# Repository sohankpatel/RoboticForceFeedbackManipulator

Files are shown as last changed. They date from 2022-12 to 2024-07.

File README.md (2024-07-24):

# RoboticForceFeedbackManipulator
Final Project for ECE 445, Manipulator with user force-feedback

This is a project I did for my Senior Design class

It is a Robotic manipulator and glove system meant to allow the wearer to "feel" forces from the robotic hand

Details are contained in the Final Paper

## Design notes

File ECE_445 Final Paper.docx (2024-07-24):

By

Noah Franceschini

Sohan Patel

Final Report for ECE 445, Senior Design, Fall 2022

TA: Jason Paximadas

6 December 2022

Project No. 3

HAPTIC FEEDBACK GLOVE

Abstract

Our project was a user-worn device similar to a VR haptic feedback glove. It is designed to apply a variety of forces back to a user depending on the force exerted by a separate manipulator. We created the user-worn device as well as a rudimentary gripper. We were able to implement a finger tracking algorithm, and developed a method to measure force applied by the manipulator and apply it back to a user's hand. We were unable to get force feedback fully working due to unforeseen issues with electronics chosen for the project.

Contents

1. Introduction 1

1.1 Subsystem Overview 1

2. Design 3

2.1 Design Procedure 3

2.2 Design Details 3

3. Verification 7

3.1 Glove 7

3.2 Manipulator 8

3.3 Microcontroller 9

3.4 Power 9

4. Costs 11

4.1 Parts 11

4.2 Labor 12

5. Conclusion 14

5.1 Accomplishments 14

5.2 Uncertainties 14

5.3 Ethical considerations 15

5.4 Future work 15

References 16

Appendix A Requirement and Verification Table 17

# 1. Introduction

From Zoom calls for work and instructional material, to YouTube videos where we can explore vast worlds through our screen, the way we interact with our world has become increasingly virtualized, but only in sight and sound. It is difficult to interact with objects through a screen such that if a material is not immediately in front of you then there is no good way to feel its physical properties. Our solution to this problem is the haptic feedback glove.

The haptic feedback system comes in two distinguishable parts: a robotic manipulator and a wearable glove. The robotic manipulator is a 3D printed robotic hand controlled via servos. The robotic fingers’ positions mimic that of the user’s hand in the glove and each finger reports back its current draw to tell the glove system how much force the servos are applying on whatever object the manipulator is holding. As for the glove, it applies forces read from the manipulator system back onto the user’s hand as to recreate a sense of touch from the manipulator’s held object, thus allowing users to interact with objects from a distance.

Throughout this report, we detail the intended design aspects of our project and how the system should cohesively mesh into the final product. Though, despite our best efforts, our end product did not hit the goals that we wanted it to. We were unable to get the force feedback part of the glove working properly; however, we were able to successfully implement finger tracking as well as successfully implement all of our components on our printed circuit board (PCB).

## 1.1 Subsystem Overview

There are four main components to our system: the glove subsystem and the manipulator subsystem, the microcontroller subsystem, and the power subsystem. The glove subsystem is a wearable device that is responsible for applying forces to the user’s hand and keeping track of the user’s finger position. The manipulator subsystem is a 3D-printed robotic hand that mimics the glove’s finger positions and relays forces back to the glove subsystem. The microcontroller subsystem is the mediator of the glove and manipulator subsystem as it receives both the position and force information from both systems and tells each respective subsystem where it should be and what forces it should be applying. As for the power subsystem, that consists of a lithium-polymer (LiPO) battery that powers our entire PCB through a buck converter as well as the electronic speed controllers (ESC) that we use for our brushless motors.

To consider this project successful, we instituted these requirements that must be met by our design:

- Measure and apply forces back to user’s hand to at least 10 lbs of force
- Have a latency of less than 1 second
- Support dynamically changing the force to match anything from slight resistance to fully stopping movement

Our reasoning for these requirements hinges on what we believed would create a quality experience for the user. We wanted to apply at least 10 lbs of force back to the user as that is about the pinch strength of most people [1], where pinch strength is the measure between what a person can hold between a finger and a thumb, and we wish to restrain the users movement of up to that amount of force. For the user to have a responsive experience with the glove, we figured that a full control loop should take less than a second. Lastly, we wanted our glove to provide a range of forces as to allow the user to have a better feel for what the manipulator was interacting with. The range of forces should allow the user to tell whether the manipulator is encountering a solid object or something softer like a stress ball.

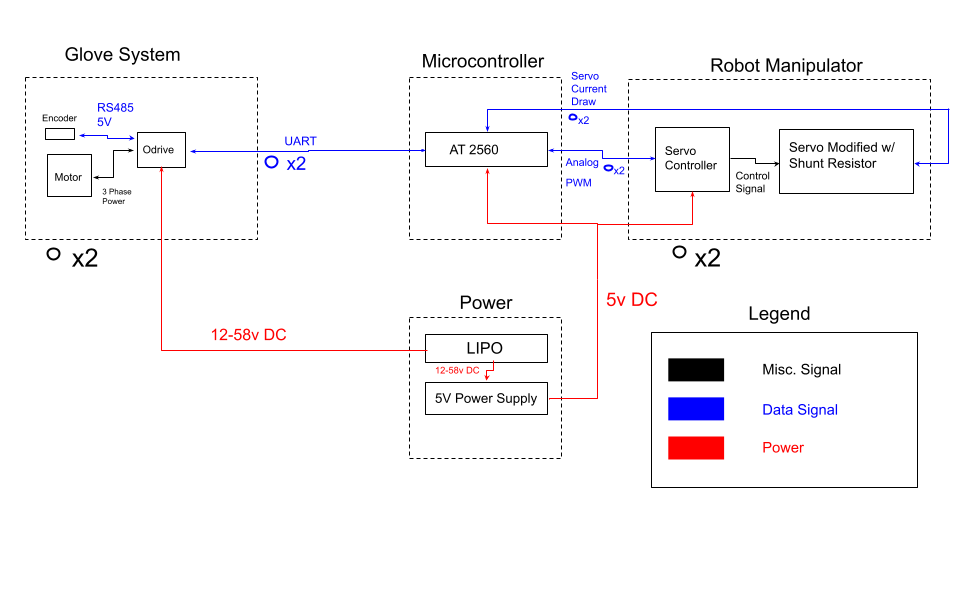
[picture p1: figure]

Figure 1: Project block diagram

# 2. Design

## 2.1 Design Procedure

### 2.1.1 Glove

We originally decided to use servos to apply forces to the user’s hand, but they are not able to change forces, nor report back position without extensive modifications. We then looked into brushless motors and their controllers and found a few options: ESC, VESC [2] and ODrive [3]. ESCs, while cheap, can't support encoders and therefore can’t measure motor position. VESCs do support encoders and are readily available, but low-cost designs use a chip in the DRV family from Texas Instruments that is in shortage at the time of this report, so we were unable to source them. The final option was ODrive, it is a robust system that has very precise control over torque and can be communicated with over the universal asynchronous receiver-transmitter protocol (UART) to send position information, the downside is that they are quite pricey and require a fair bit of configuration before use.

### 2.1.2 Manipulator

We decided on using simple hobby servos for this component. The alternatives would have been another controller with precise positioning like the ODrive, but we felt it would be overkill for our purposes.

### 2.1.3 Microcontroller

The microcontroller originally needed to support 5 UART devices, the only Atmel product we found that was readily available, well documented and inexpensive was the ATmega2560 [4]. The PCB also had a high side current sensing circuit that will be discussed in detail in a later section.

### 2.1.4 Power

The power system had a couple requirements. The first being 12-58V DC and 120A to the ODrives, the best candidate for this would be a LiPO battery, as they support the high discharge rate and a 6s battery has a voltage of 22.2V.

## 2.2 Design Details

### 2.2.1 Glove

The glove was relatively simple to design, as ODrives can do all that we need them too right from the factory. They are able to communicate with the AMT212B-V encoder over RS485 with some slight configuration. Using the ODrive and this encoder, we not only can drive the motor to an extremely precise position, we can also poll it via UART for that position. These UART messages are created using the ODrive Arduino library [3], which turned out to have bugs that we corrected. More specifically, the command for getting the encoder position was incorrect. It outputs this position as a positive or negative number in units of full rotations, so .5 would be a half turn clockwise. We controlled the force on the user's hand by setting the ODrive to a low current cutoff, just enough to take up slack in the strings attached to the user’s fingers. We can then increase this cutoff via UART proportionally to the current consumed by the servos to pull back with increasing intensity on the wearer’s hand. We found that 40A of current is enough to reach 10 lbs of force on the user’s hand, with the correlation being roughly linear down to zero force. The motors and encoders were mounted to an arm sleeve, with strings attached to fingers of a glove.

### 2.2.2 Manipulator

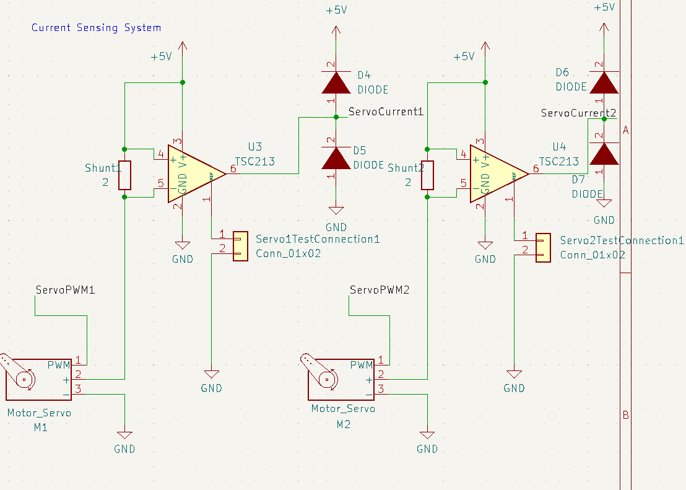
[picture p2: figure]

Figure 2: Current Sensing Circuit

The manipulator was one of the most important parts of our project, as it is where the entire idea of force feedback comes from. The manipulator was moved with servos that had high side shunt resistors. The voltage across these resistors is proportional to current via Ohm’s Law. We can’t drop the full 5V across this resistor however, as the servos pull 3A. This would lead to a 15W power dissipation which is quite high and it would be difficult to find resistors rated for that power. It would also mean we would have to consider other factors such as heat sinking or actively cooling the board. Because of this, we decided on a lower voltage drop of .1V. We chose a resistor of 30 mΩ. This allows us to drop just under .1V at 3A of current, at a much lower power dissipation. The issue with this is that the analog to digital converter (ADC) in the microcontroller unit (MCU) is only 10 bits, it can only read 1024 values. If we were to use the .1V directly, we would only be able to cover 20 discrete values. The concern we had was that this would lead to distinct steps that the user could feel as the force increased. In order to mitigate this, we decided to use an amplifier circuit to increase that .1V to the full 5V range, in order to take advantage of the full range of the ADC (Figure 2). We used a TSC213 [5] integrated circuit (IC), which has a gain of 50, which nicely landed us in the 5V range. There are some additional diodes in the schematic that are for protecting the MCU in the case that the voltage goes over 5V and could damage the ADC, but they were left out in the final PCB.

### 2.2.3 Microcontroller

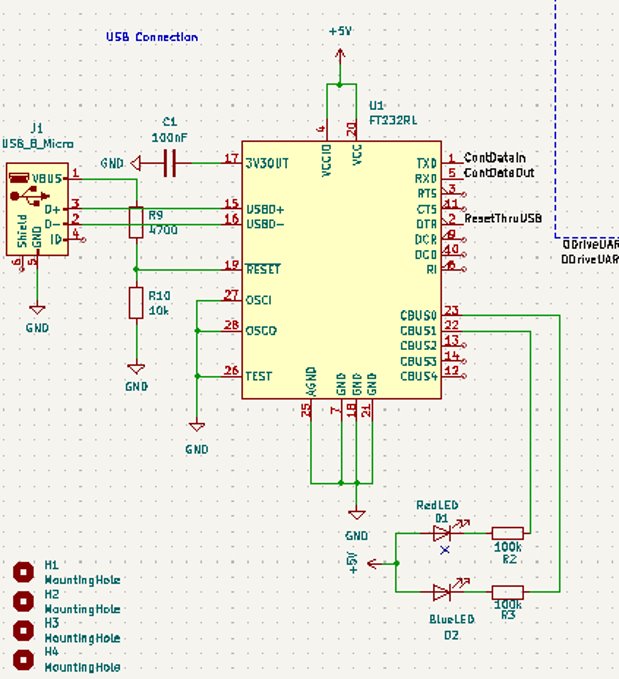
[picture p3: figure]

Figure 3: FTDI programming circuit

The microcontroller we chose was the Atmel ATMEGA2560. It was chosen because not only is it the same processor as an Arduino Mega, it is also capable of five UART connections at once. This was more important in our original design with five ODrives, but most arduino boards do not support more than one UART device. We wanted to use a MCU that was also on an Arduino board so we could flash an Arduino bootloader and program it via the Arduino integrated development environment (IDE). This would also allow us to stream serial information back to our computer for debugging. To do this we used a chip from FTDI that uses UART 0 on the MCU to flash programs (Figure 3). We also exposed the MCUs in-circuit serial programming (ICSP) pins and joint test action group (JTAG) pins in the case that the USB programming chip failed. We used the ICSP pins to flash the Arduino bootloader to the board and were able to program it over USB. However, we ended up not using the FTDI programmer in the final project because we found it easier to just flash over ICSP using an Arduino Uno.

### 2.2.4 Power

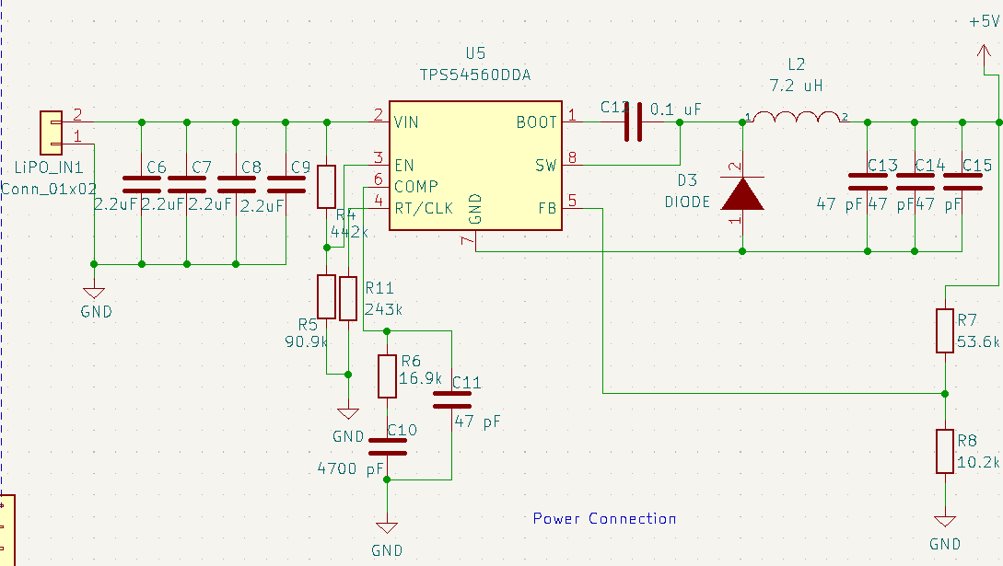
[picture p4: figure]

Figure 4: Buck Converter circuit

The power subsystem was quite simple. We chose a 6S, 5Ah, 45C LiPO to power the entire project. It can provide 22.2V at 5*45A, which is 225A, far more than the 120A we need. However the microcontroller only runs on 5V. We needed to step down the voltage and had 2 options, a linear regulator or buck converter. We ended up using a buck converter because a linear regulator would have to dissipate a large amount of power and would likely need to be cooled and would cause us to need additional design considerations, similarly to if we tried to dissipate 15W across a resistor. We chose a TPS54560DDA [6] chip from TI. It has an input voltage of up to 60V and can output 5V at 5A, which should be enough to run our entire project. The downside of it compared to a linear regulator is that it needs a fair amount of surrounding circuitry (Figure 4) in order to set the device’s parameters. We also found that we should have added large output capacitors due to the transient loads produced by the servos turning on that ended up browning out the MCU.

# 3. Verification

## 3.1 Glove

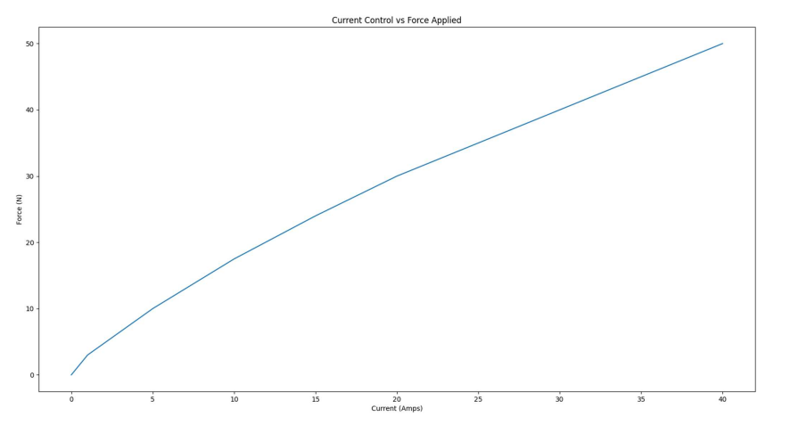
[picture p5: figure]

Figure 5: Current vs Force

The glove subsystem verifications were quite straightforward, to test UART we not only used an arduino mega to send commands, we also used an oscilloscope to view the waveforms. We were actually able to find an error in the ODrive Arduino library thanks to this. When we were receiving nothing in response when polling for encoder position, we decided to decode the UART signal and found that the ODrive was responding with random values. Upon diving deeper we found that the command being sent with the GetPosition() function was deprecated and meant for the old open-source ODrive 3.6, whereas we were using ODrive Pro. Figure 5 contains the forces we measured from the ODrive when applying various currents. Interestingly, this is somewhat linear which was not expected due to motor torque vs current not generally following a linear pattern. We were easily able to apply 10 lbs of force and could likely apply more, as the ODrive is capable of 60A sustained without external cooling. The final verification was if the glove could actually stop the user’s hand completely, we found that this was absolutely the case. When wearing the glove and attempting to close our hands it was easily able to keep them open with the 40A current value, which applied 50N of force.

## 3.2 Manipulator

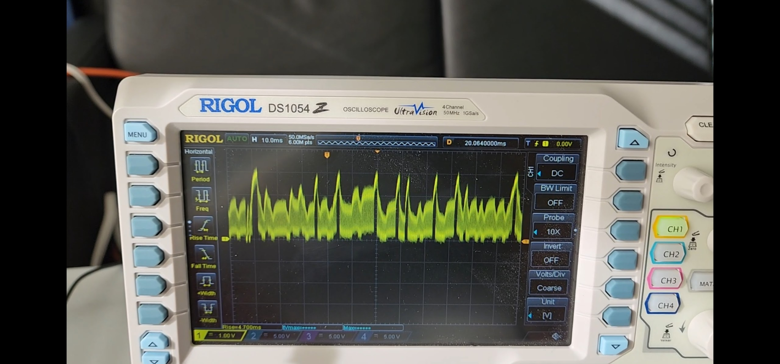
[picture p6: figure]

Figure 6: Oscilloscope output of current draw

The manipulator was a bit more involved to debug, but was a similar process to the glove when testing servo communication via pulse width modulation (PWM). We measured the output of our PCB using an oscilloscope and found that it was, in fact, varying the PWM duty cycle in a way the servo could understand. We tested by sweeping it from 0 to 180 degrees and found that it did follow precisely. We were also able to get it to mimic finger positions quite easily by polling the ODrive encoder position and converting it to an angle between 0 and 180, then commanding the servo to that location. The most difficult part to verify was the voltage across our shunt resistor.

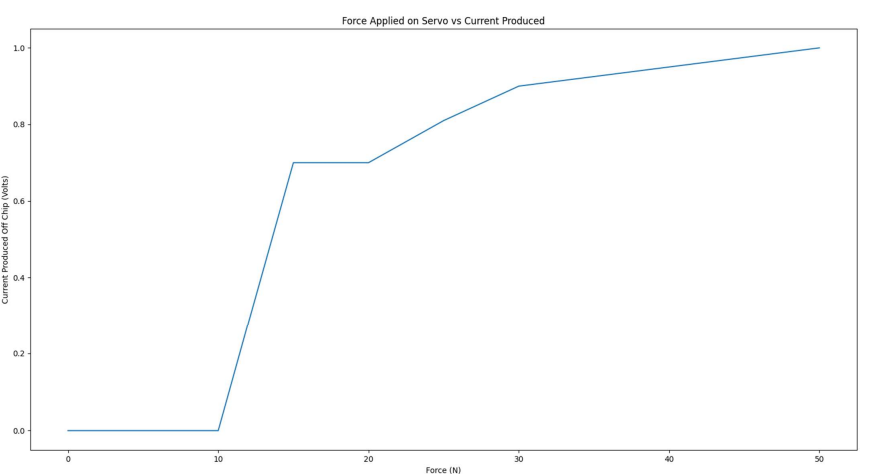
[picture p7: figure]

Figure 7: Servo force vs voltage

This graph (figure 7) is the measurement of the voltage across our shunt resistor against the force of the servo. This oddly shaped graph is due to unexpected behavior of the servo’s controller. It would rapidly switch on and off, creating a waveform shown in figure 6. This caused our MCU to not sample the data correctly as it was more or less a floating signal between 0 and the voltage we wanted. Even when averaging it over time we were unable to get a usable signal, as the ADC was measuring mostly random values. Due to this we were unable to get force-feedback working.

## 3.3 Microcontroller

The microcontroller’s verification went hand-in-hand with moving the servos and polling the ODrives. It had to facilitate the communication between glove and manipulator, as well as do so quickly. To test both of these on our custom board, we uploaded a program that simply mirrored ODrive position to the servo’s and found that they would mimic each other’s movement. To make sure the latency was low, we used an Arduino MEGA, which has the same MCU as our custom board and output the time the loop took to run to the serial monitor. The control loop ran in about 100ms, which updated the position 10 times in that loop. This means it took roughly 10ms to move the servos when the ODrives were moved, plenty fast for our use case.

## 3.4 Power

The power system was verified by measuring the output of our buck converter with a multimeter and confirming the voltage output was about 5V DC. We tested if changes to the input of the buck converter would affect the output in cases such as stopping a motor suddenly, where the voltage would increase slightly as current was sent back to the battery. We did this by rapidly changing the voltage input from 12 to 30V DC and found no change in the output. We did however, run into problems with transient loads generated by the servos moving. This would cause the board voltage to drop significantly, into the 3v range, which caused our ATMEGA 2650 to reset due to low power. This could have been solved by adding output capacitors to our design to help compensate for the sudden power demand.

# 4. Costs

## 4.1 Parts

Table 1 Parts Costs
Part | Manufacturer | Retail Cost ($) | Bulk Purchase Cost ($) | Quantity | Aggregated Cost ($)
ODrive Pro | ODrive Robotics | 229.00 | 229.00 | 2 | 458.00
Servo 4-Pack | Deegoo | 20.99 | 20.99 | 1 | 20.99
1kg PLA | Hatchbox | 25.00 | 25.00 | 2 | 50.00
12g Wire | Haerkn | 22.98 | 22.98 | 1 | 22.98
TPS54560DDA | Texas Instruments | 6.86 | 6.86 | 6 | 41.16
47 pF Capacitor | KEMET | 0.34 | 0.232 | 12 | 2.78
2.2 uF Capacitor | KEMET | 0.80 | 0.466 | 12 | 5.59
4700 pF Capacitor | KEMET | 0.31 | 0.31 | 4 | 1.24
0.1 uF Capacitor | KEMET | 0.13 | 0.093 | 15 | 1.40
16.9 kΩ Resistor | Vishay / Dale | 0.16 | 0.14 | 10 | 1.40
53.6 kΩ Resistor | Vishay / Dale | 0.16 | 0.063 | 10 | 0.63
10.2 kΩ Resistor | Bourns | 0.10 | 0.029 | 10 | 0.29
100 kΩ Resistor | Bourns | 0.65 | 0.479 | 10 | 4.79
10 kΩ Resistor | Bourns | 0.47 | 0.358 | 10 | 3.58
Schottky Diodes | Vishay General Semiconductor | 0.54 | 0.438 | 12 | 5.25
7.3 uH Inductor | Wurth Elektronik | 3.48 | 3.48 | 1 | 3.48
10 uH Inductor | KEMET | 0.38 | 0.241 | 10 | 2.41
USB A Connector | GCT | 0.87 | 0.87 | 1 | 0.87
8 MHz Crystal Oscillator | ECS | 0.97 | 0.97 | 1 | 0.97
Solder Paste | Chip Quik | 15.84 | 15.84 | 1 | 15.84
ATMEGA2560 | Microchip Technology | 17.79 | 17.79 | 2 | 35.58
Solder Wick | Chip Quik | 1.99 | 1.99 | 2 | 3.98
Flux | Chip Quik | 9.95 | 9.95 | 1 | 9.95
442 kΩ Resistor | Yageo | 0.04 | 0.037 | 10 | 0.37
TSC213 | STMicroelectronics | 2.59 | 2.59 | 8 | 20.72
Red LEDs | Stanley Electric | 0.40 | 0.40 | 6 | 2.40
7.2 uH Inductor | Wurth Electronics Inc. | 3.57 | 3.57 | 3 | 10.71
90.9 kΩ Resistor | Stackpole Electronics Inc. | 0.08 | 0.073 | 10 | 0.73
243 kΩ Resistor | Panasonic Electronic Components | 0.10 | 0.088 | 10 | 0.88
Mini-USB Connector | Adam Tech | 1.29 | 1.29 | 3 | 3.87
16 MHz Crystal Oscillator | Wurth Electronics | 0.40 | 0.40 | 4 | 1.60
4.7 kΩ Resistor | Stackpole Electronics Inc | 0.03 | 0.024 | 10 | 0.24
10 kΩ Resistor | Stackpole Electronics Inc | 0.08 | 0.073 | 10 | 0.73
22 pF Capacitor | Vishay Vitramon | 0.45 | 0.414 | 10 | 4.14
0.03 Ω Resistor | Ohmite | 0.43 | 0.40 | 10 | 4.04
47 uF Capacitor | Samsung Electro-Mechanics America | 0.36 | 0.311 | 10 | 3.11
PCBs | PCBWay | 1.00 | 1.00 | 10 | 10.00
Rush Order PCBs | 4PCB | 33.00 | 33.00 | 3 | 99.00
Shipping and Handling | Digikey / Mouser | 60.00 | 60.00 | 1 | 60.00
Part Subtotal | | | | | 915.70
Labor Hours | Noah and Sohan | $48/hr | | (10 Hours each week * 2 people * 9 weeks) | 8,640.00
Total | | | | | 9,555.70

## 4.2 Labor

Table 2 Schedule

Week | Task
10/2-10/8 | Design PCB (Noah) Purchase electronic components (Sohan) Purchase PLA (Sohan)
10/9-10/15 | Order PCB (Sohan) Receive PLA (Noah + Sohan) Begin Printing/Designing robotic hand (Noah + Sohan) Begin Designing Glove (Noah + Sohan)
10/16-10/22 | Receive electronics (Noah + Sohan) Configure ODrive (Sohan) Test Servos (Noah) Test PCB Components on a breadboard (Noah) Test Power System (Sohan) Continue designing hand (Noah + Sohan) Continue designing glove (Noah + Sohan)
10/23-10/29 | Solder PCB components into the PCB (Sohan) Assemble hand (Noah) Assemble Glove (Noah) Combine all subsystems together (Noah + Sohan) Begin implementing finger tracking algorithm (Noah + Sohan)
10/30-11/5 | Finish implementing finger tracking algorithm (Noah + Sohan) Begin implementing force feedback (Noah + Sohan)
11/6-11/12 | Continue implementing force feedback (Noah + Sohan)
11/13-11/19 | Finish implementing force feedback (Noah + Sohan) DEMO TO TA
11/20-11/26 | FALL BREAK Last minute fixes/tweaks (Noah + Sohan)
11/27-12/3 | Final Demos (FINISH)

# 5. Conclusion

## 5.1 Accomplishments

Despite being unable to implement force-feedback with the glove, we still managed to meet most of our project’s goals that we set out to accomplish. In terms of high-level requirements, we implemented the finger-tracking algorithm efficiently enough for the latency between hand movement and manipulator movement to be ~100ms. Although active force-feedback we could not accomplish, we were able to to test the motors with a variety of resistive forces and try them on the hand as shown in figure 5. Lastly, we managed to deliver upwards of 10 lbs of force as shown in figure 5 as well. In testing that amount of force was enough to completely arrest our hand movements.

Other small goals that we achieved were with finger tracking and the final PCB design. After we assembled the glove and manipulator system and after a bit of parameter tuning, we discovered that our finger tracking algorithm worked. When we would squeeze our fingers shut we found that the manipulator would track our fingers with ~5° of deflection. Another accomplishment was that our final PCB design proved to be successful as we could run all of the software off of the ATMEGA2560 on the PCB as well as all surrounding components such as the current sensing circuit.

Where these successes leave our project now is that we have a manipulator subsystem that accurately mimics the glove subsystem as well as has the potential to provide force feedback given that we could sample the current sensing circuit more accurately.

## 5.2 Uncertainties

Our failures come from unexpected difficulties with both the buck converter and the hobby servos that we used in our project. The buck converter in our design had an issue where when the servos were actuating the output voltage would sharply decrease from 5.3V to ~3.5V. This issue would cause the circuit to brown out and consequently cause our microcontroller to crash. After some investigation we believe that a large output capacitor would help mitigate the transient loads that the servos place upon the power system. Our reasoning for an output capacitor is that the servos draw more current than the buck converter can supply at its current switching frequency when the servos are holding their position. An output capacitor can act as a reservoir of charge for when the system is in a steady state, dissipating this charge when the servos require more current, keeping the 5V line from dropping below 5V as the buck converter attempts to switch switching frequencies to make up for the inadequate current supply.

Another issue was our choice of servos, though the problems did not manifest until trying to implement force feedback. When probing the voltage drop across the shunt resistor in the current sensing circuit, we noticed that the signal was relatively very noisy as seen in figure 7. What we believe is happening is that the servo controller rapidly turns the servo on and off to reach a desired position rather than a smooth increase in current to move the servo that other more expensive motor controllers do. The problem this controller causes is that it creates such a noisy signal that the sampling in our ATMEGA2560 is unable to correctly read the spike in the voltage drop and instead retrieves a value somewhere in between. This effect caused our force feedback algorithms in tests to be unresponsive at best and would frequently stutter at worst, neither of which felt like a proper force feedback mechanism. We attempted several solutions to remedy the spikes in voltage drop. We tried averaging samples over a short window to smooth out the force feedback. We tried using the maximum value over a short period to see if we could obtain the voltage spike seen in figure 7. We also tried different force coefficients to lessen the impact that large spikes would generate and none of those approaches proved fruitful. We believe that the best solution to this problem is better motor controllers such that when the manipulator motors are met with resistance they linearly increase in current draw rather than flickering on and off when met with resistance.

## 5.3 Ethical considerations

According to the IEEE Code of Ethics section 7.8 subsection II.9 [7], we have a responsibility to not harm others during the course of creating and also testing our project. The one concern that comes with a haptic-feedback glove is that the motors will apply torque to the user’s hand and could cause bodily harm to the user. We have implemented a couple of risk mitigating factors into our design that should prevent any injury to the user. The first factor is a maximum current cutoff for the brushless motors using the ODrive. Once the motor current draw exceeds a predefined threshold the ODrives enter a fail state where the motors will no longer apply any forces to the user's hand until the program is reset. The cutoff is currently set to 50A which is about 10 lbs of force, any force exceeding that will shut down the motor such that we do not injure the user. Another feature we implemented was that the motors stop pulling on the user’s hand once at the home position. The home position in this case is a hand in a resting open position. We implemented this safety feature so as to not allow the motors to pull back on the user’s hand any further than what is comfortable so that we do not bend the fingers too far back and injure the user.

According to the IEEE Code of Ethics section 7.8 subsection I.5 [7], we must always strive to seek honest and critical feedback on our ideas. Hearing feedback can often be difficult, but we did keep an open mind to any suggestions made by the professors or our teaching assistant. In this case, our teaching assistant on numerous occasions made suggestions as to how we could improve our design. The first being how to restructure our PCB layout as to reduce noise across analog to digital components. Another suggestion was made as to how we could implement the current sensing circuit. In this design process we were happy to hear feedback and criticism so that we could produce the best project possible and in doing so we believe that feedback made our product better.

## 5.4 Future work

If we were to do this project again, there are several improvements that could be made. As suggested in the previous section, we would use better servos/controllers as the noise from the servos made force feedback nearly impossible to implement. We would also place a large output capacitor on our buck converter to prevent the servos from browning out our power supply, removing the need for a benchtop power supply. Another problem that we would take more heed with is assembling the PCB. Several times during the construction process we mismanaged wires and accidentally switched 5V and ground resulting in any active components on the PCB to be damaged or destroyed.

# References

[1] T. Nilsen, M. Hermann, C. S. Eriksen, H. Dagfinrud, P. Mowinckel, and I. Kjeken, “Grip force and pinch grip in an adult population: Reference values and factors associated with Grip Force,” Scandinavian Journal of Occupational Therapy, vol. 19, no. 3, pp. 288–296, 2011.

[2] B. Vedder, “Vedderb/BLDC-hardware: Brushless DC Motor Controller from Benjamin Vedder,” GitHub, 03-Oct-2015. [Online] Available: https://github.com/vedderb/bldc-hardware.

[3] “Getting Started.” Getting Started - ODrive Pro Documentation 0.6.3 Documentation, ODrive Robotics, 2022, [Online] Available: https://docs.odriverobotics.com/v/latest/getting-started.html.

[4] “Atmega2560-16AUR: Digi-Key Electronics.” Digi, Digi-Key Electronics, 2022, [Online] Available: https://www.digikey.com/en/products/detail/microchip-technology/ATMEGA2560-16AUR/2357022.

[5] “TSC211ICT STMicroelectronics: Mouser.” Mouser Electronics, Mouser Electronics Inc., 2022, [Online] Available: https://www.mouser.com/ProductDetail/STMicroelectronics/TSC211ICT?qs=iLbezkQI%252BsjsYAfcpKipFQ%3D%3D.

[6] “TPS54560,” Texas Instruments., [Online] Available: https://www.ti.com/product/TPS54560.

[7] “IEEE Code of Ethics.” IEEE, 2022, [Online] Available: https://www.ieee.org/about/corporate/governance/p7-8.html.

# Appendix A Requirement and Verification Table

Table 3 Glove Subsystem Requirements and Verifications
Requirement | Verification | Verification status (Y or N)
Must send position information and receive force information | Using an Arduino MEGA, confirm test program functionality. Read encoder positions and send force data to board and manually confirm forces. | Y
Variable Resistance from 0 to 10lbs | Using ODrive Current control, adjust the target torque value and confirm motor resistance changes to match the input | Y
Completely Arrest hand movement and hold in place | Using ODrive position control, set a target position and try to move the glove from the set position, +/- 10° of deflection is acceptable | Y

Table 4 Manipulator Subsystem Requirements and Verifications
Requirement | Verification | Verification status (Y or N)
Must be controlled via servos and have 180° of motion | Using an Arduino MEGA, control each servo independently and confirm that each one reaches 180° (+/- 5° on each side) even after the entire hand is assembled. | Y
Must report current consumed by servos via a shunt resistor and a high-side current sensing amplifier chip | Apply increasingly larger forces (between 0-50N) on the fingers of the manipulator. At each 5N increment we will record the output of the amplifier chip so that we know what kind of force to apply back to the glove at that voltage. | Y
Receive position commands via PWM and mimic finger positions of the glove subsystem | Ensure that actual finger placement versus manipulator finger placement is within 5° of each other. | Y

Table 5 Microcontroller Subsystem Requirements and Verifications
Requirement | Verification | Verification status (Y or N)
Receive analog signal and have sufficient variation for ADC conversion | Target a variation of 0-5v +/- .1V for the input to the ADC | Y
Send and receive data | Using a test program, verify that the Odrives are being properly controlled by the MCU | Y
Send position data over PWM to Servo | Using a Oscilloscope, verify the correct waveform and frequency, then confirm the servo is moving in response to the signal. | Y
Process data and send commands quickly (Less than 1s) | Using the glove, change the position of the encoder and verify that the time for the manipulator to move is less than 1s | Y

Table 6 Power Subsystem Requirements and Verifications
Requirement | Verification | Verification status (Y or N)
5v power from buck converter to microcontroller | Using a multimeter, confirm voltage output is between digital high (5v-7v) within +/-.1v | Y
Lipo power system must be isolated from 5v power supply | Using a multimeter, monitor the voltage across the 5v power rail from the buck converter. We will rotate the brushless motors quickly and suddenly bring them to a halt. If the 5v | Y

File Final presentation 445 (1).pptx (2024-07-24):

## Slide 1

Haptic Feedback Glove
Sohan Patel and Noah Franceschini

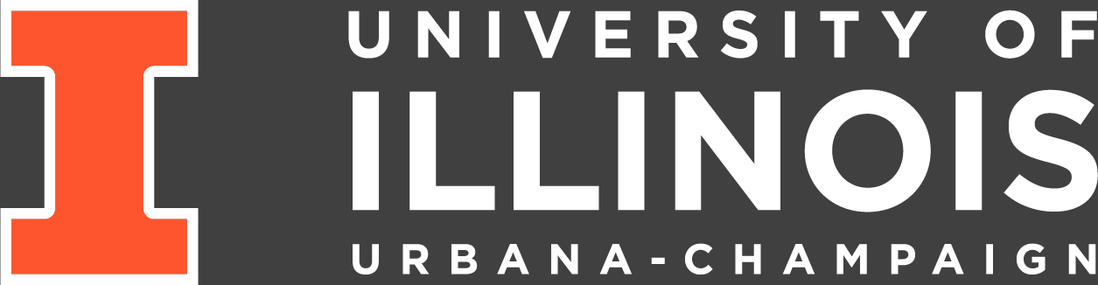
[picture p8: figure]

12/6/2022

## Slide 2

Agenda

Overview
Design
PCB Design
Results
Questions

ELECTRICAL AND COMPUTER ENGINEERING

GRAINGER ENGINEERING

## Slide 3

Overview

ELECTRICAL AND COMPUTER ENGINEERING

GRAINGER ENGINEERING

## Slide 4

Overview

Objectives
- The world has become increasingly virtualized and more remote than ever before
- Touch is a sense we cannot replicate without being near an object

ELECTRICAL AND COMPUTER ENGINEERING

GRAINGER ENGINEERING

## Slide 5

Solution
- Glove reads hand position and applies forces to hand
- Manipulator mimics position and measures force applied to object

ELECTRICAL AND COMPUTER ENGINEERING

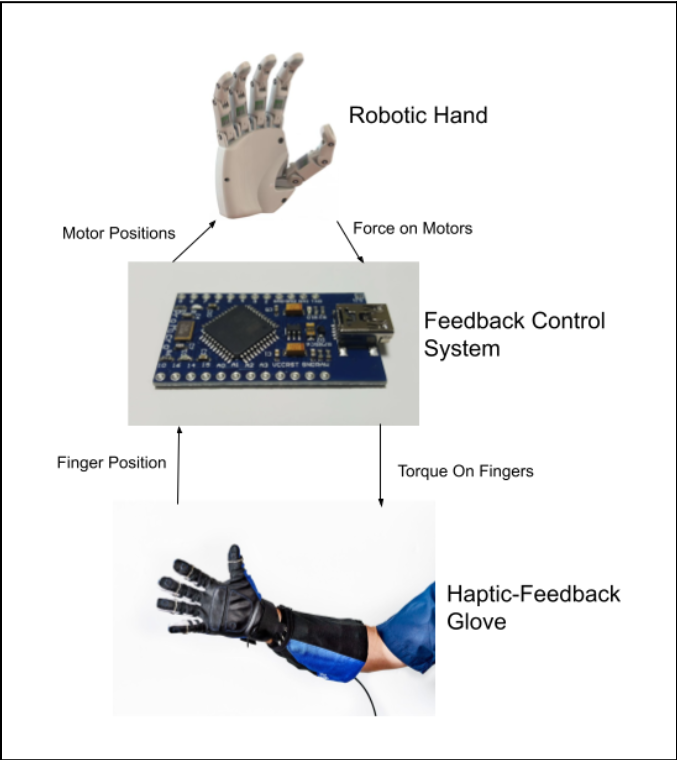
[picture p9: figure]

IMAGE

GRAINGER ENGINEERING

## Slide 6

Requirements

High Level Requirements
- Low latency of less than 1s
- Must provide a wide range of forces
- Measure and apply forces back to user’s hand of at least 10 pounds of force

ELECTRICAL AND COMPUTER ENGINEERING

GRAINGER ENGINEERING

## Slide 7

Design

ELECTRICAL AND COMPUTER ENGINEERING

GRAINGER ENGINEERING

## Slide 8

Design

Original Design
- 5 Odrives, 5 Servos
- Current sensing via shunt resistor
- ATMEGA2560 Microcontroller

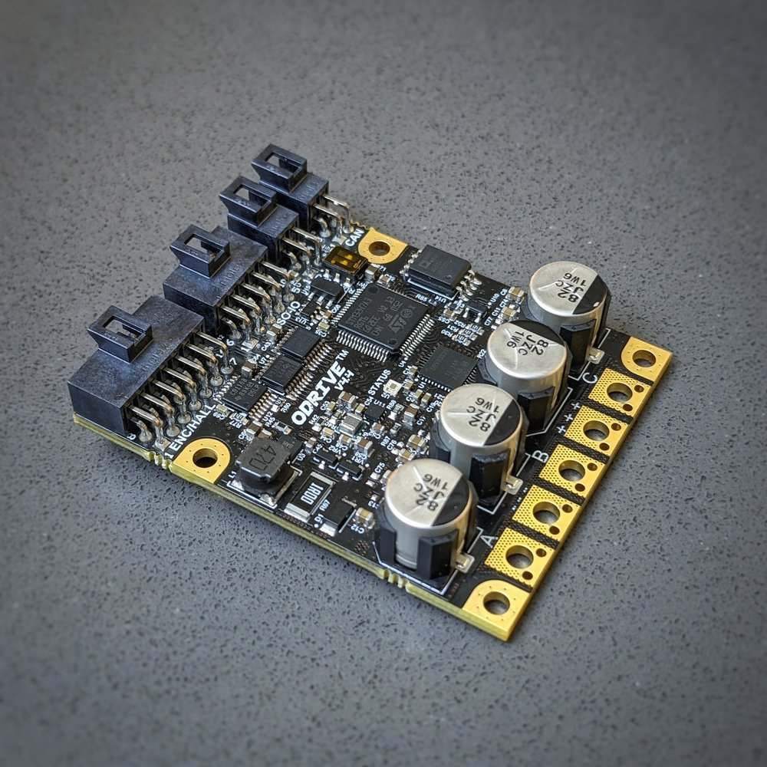
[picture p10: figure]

IMAGE / GRAPHIC

ELECTRICAL AND COMPUTER ENGINEERING

GRAINGER ENGINEERING

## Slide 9

Design

Revisions
- Haptic Feedback Mitten - All fingers and thumb
- Costs less
- Less complexity

ELECTRICAL AND COMPUTER ENGINEERING

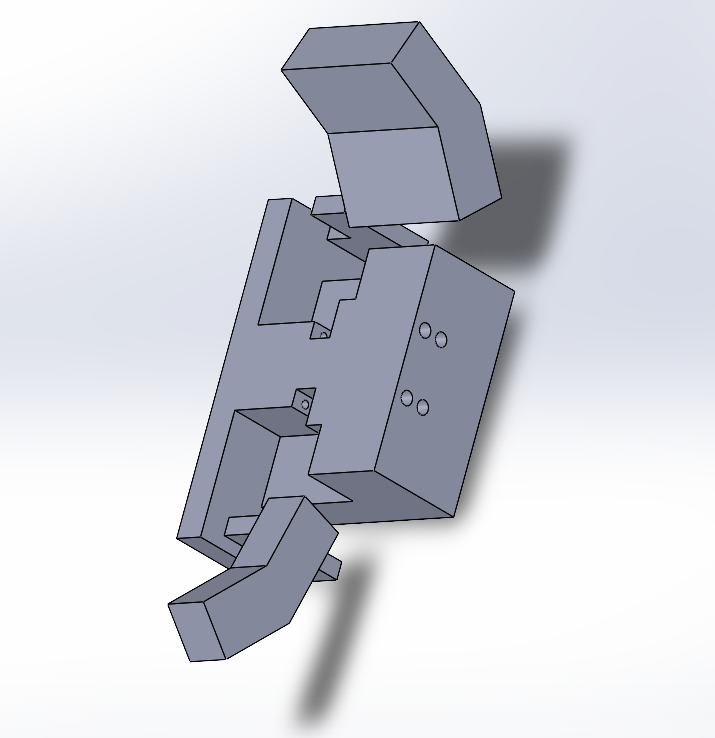
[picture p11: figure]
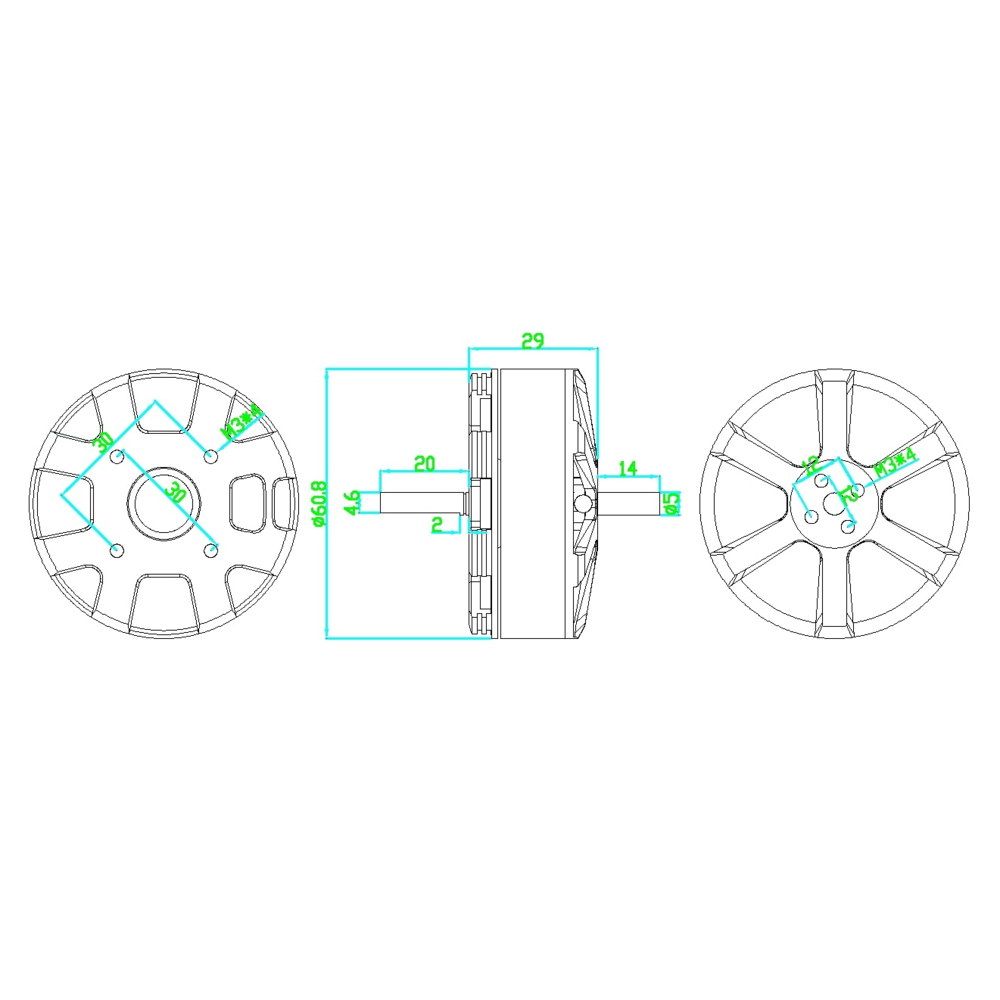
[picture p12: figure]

IMAGE / GRAPHIC

GRAINGER ENGINEERING

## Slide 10

Design

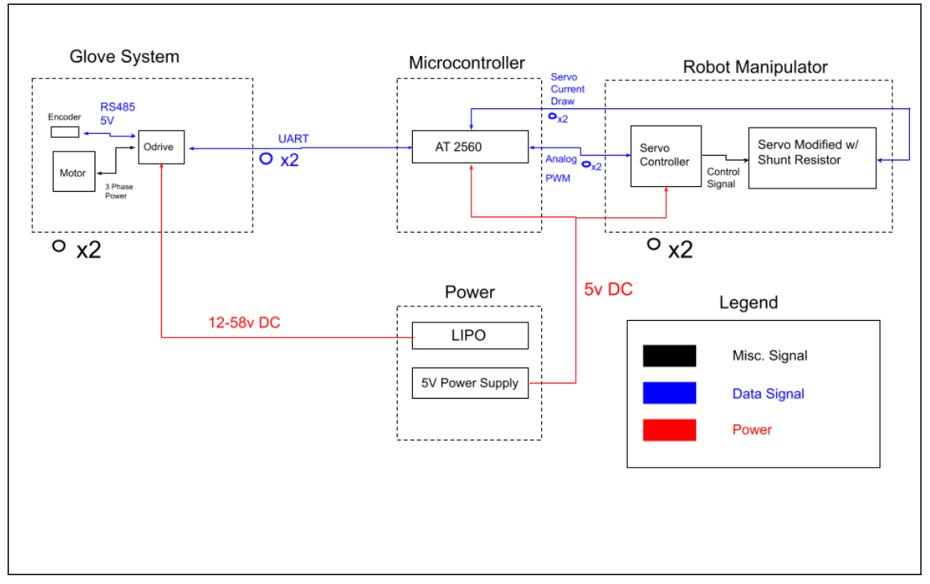
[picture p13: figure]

IMAGE / GRAPHIC

Block Diagram and Requirements
- 4 Subsystems
- Glove
- Manipulator
- Processing (Microcontroller)
- Power

ELECTRICAL AND COMPUTER ENGINEERING

GRAINGER ENGINEERING

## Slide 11

PCB Design

ELECTRICAL AND COMPUTER ENGINEERING

GRAINGER ENGINEERING

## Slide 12

PCB

Power
- 5V to Microcontroller
- Step down 24V to 5V

ELECTRICAL AND COMPUTER ENGINEERING


IMAGE / GRAPHI

GRAINGER ENGINEERING

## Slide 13

PCB

Current Sensing
- Output current value to microcontroller
- Enough voltage variation for ADC

ELECTRICAL AND COMPUTER ENGINEERING


IMAGE / GRAPHIC

GRAINGER ENGINEERING

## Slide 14

PCB

Microcontroller
- Be able to control servos (PWM) and BLDC motors (UART)
- Read current data from servos and communicate back to the glove

ELECTRICAL AND COMPUTER ENGINEERING

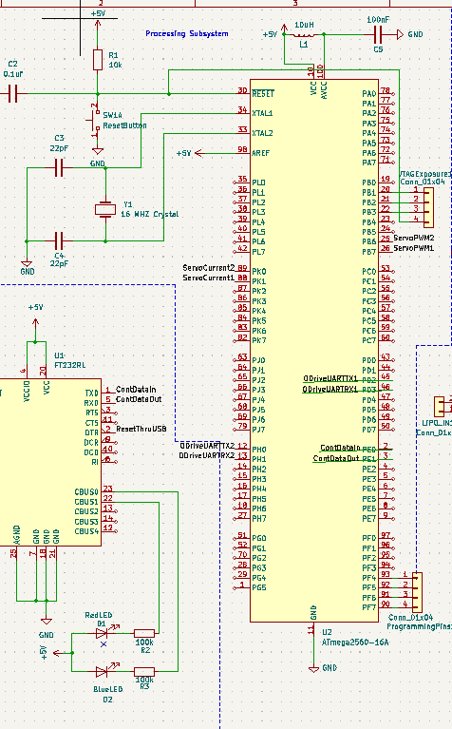
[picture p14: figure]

IMAGE / GRAPHIC

GRAINGER ENGINEERING

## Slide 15

PCB

MISC
- Micro USB for ease of programming
- Went unused in final project

ELECTRICAL AND COMPUTER ENGINEERING


IMAGE / GRAPHIC

GRAINGER ENGINEERING

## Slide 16

Results

ELECTRICAL AND COMPUTER ENGINEERING

GRAINGER ENGINEERING

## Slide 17

Results

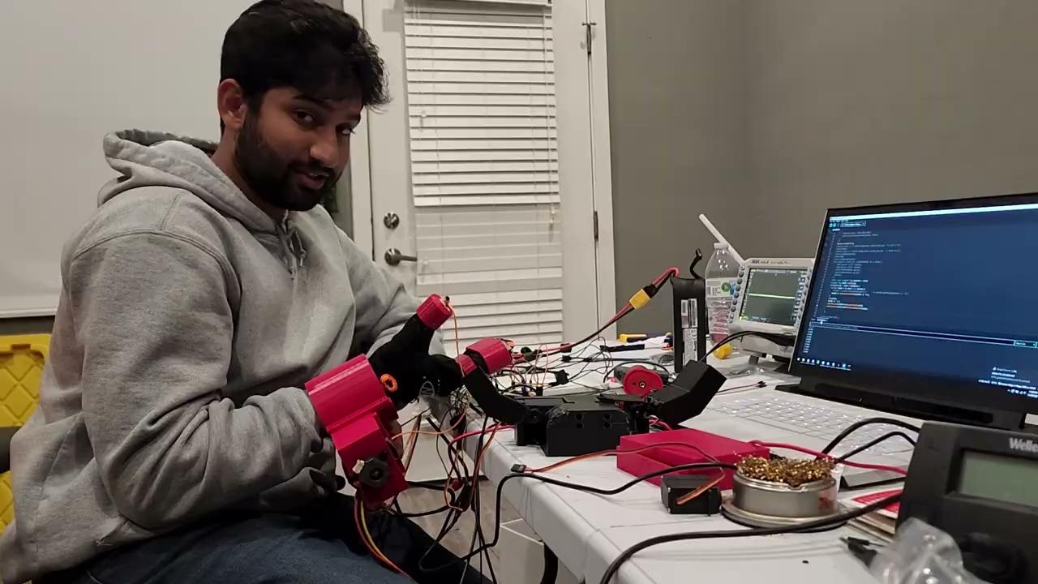
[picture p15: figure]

CHART / GRAPH

ELECTRICAL AND COMPUTER ENGINEERING

GRAINGER ENGINEERING

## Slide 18

Results


CHART / GRAPH

ELECTRICAL AND COMPUTER ENGINEERING

GRAINGER ENGINEERING

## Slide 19

Results


CHART / GRAPH

ELECTRICAL AND COMPUTER ENGINEERING

GRAINGER ENGINEERING

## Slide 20

Results

What Went Well?
- Fingers mimic positions
- All PCB systems work
- Motors can apply forces

ELECTRICAL AND COMPUTER ENGINEERING

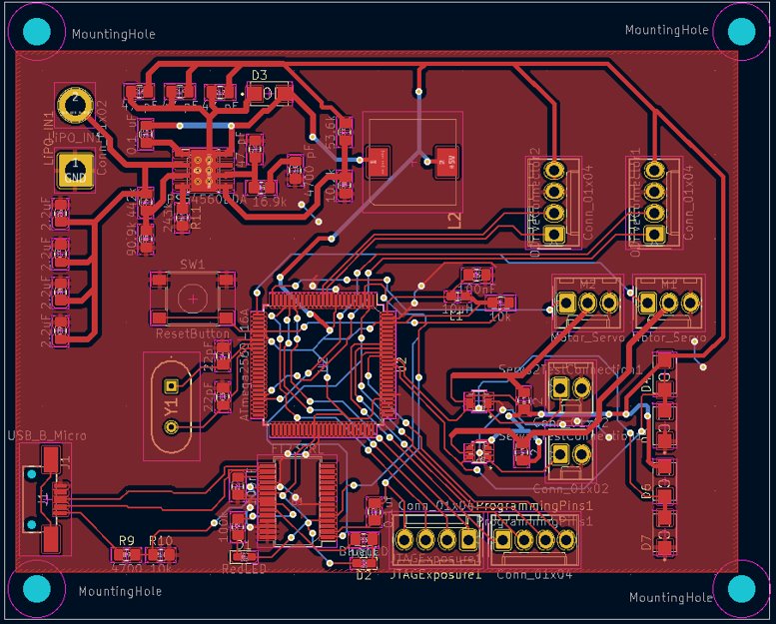
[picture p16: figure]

IMAGE / GRAPHIC

GRAINGER ENGINEERING

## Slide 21

Results

What Went Wrong?
- Poor buck converter design
- Several PCB redesigns
- Delayed, damaged and destroyed components
- Noisy servo signal

ELECTRICAL AND COMPUTER ENGINEERING

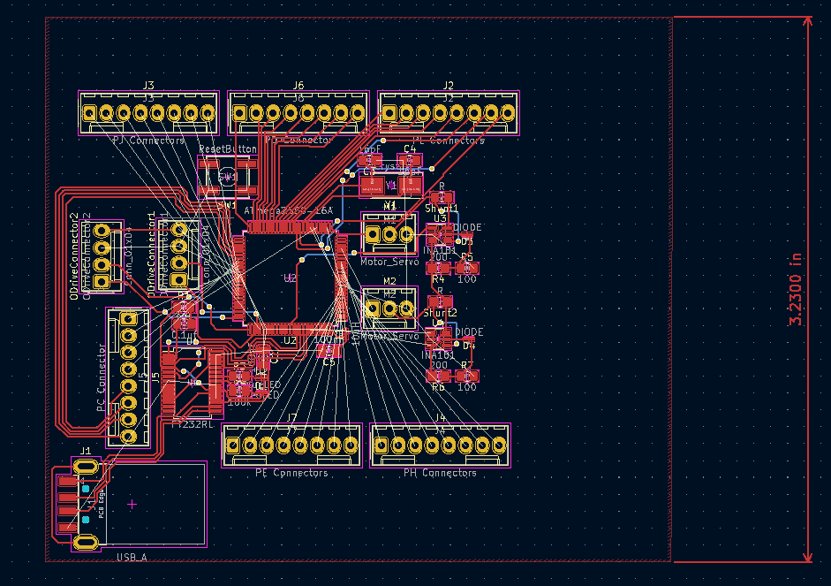
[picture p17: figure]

IMAGE / GRAPHIC

GRAINGER ENGINEERING

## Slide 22

Results

Next Steps?
- Output Capacitors
- Proper PCB footprints
- Better servo controllers
- Try not to damage components

ELECTRICAL AND COMPUTER ENGINEERING

GRAINGER ENGINEERING

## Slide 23

Questions?

ELECTRICAL AND COMPUTER ENGINEERING

GRAINGER ENGINEERING

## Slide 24

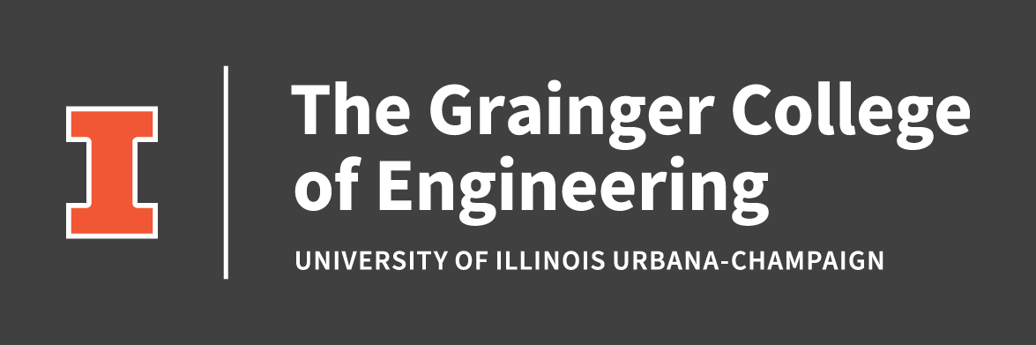
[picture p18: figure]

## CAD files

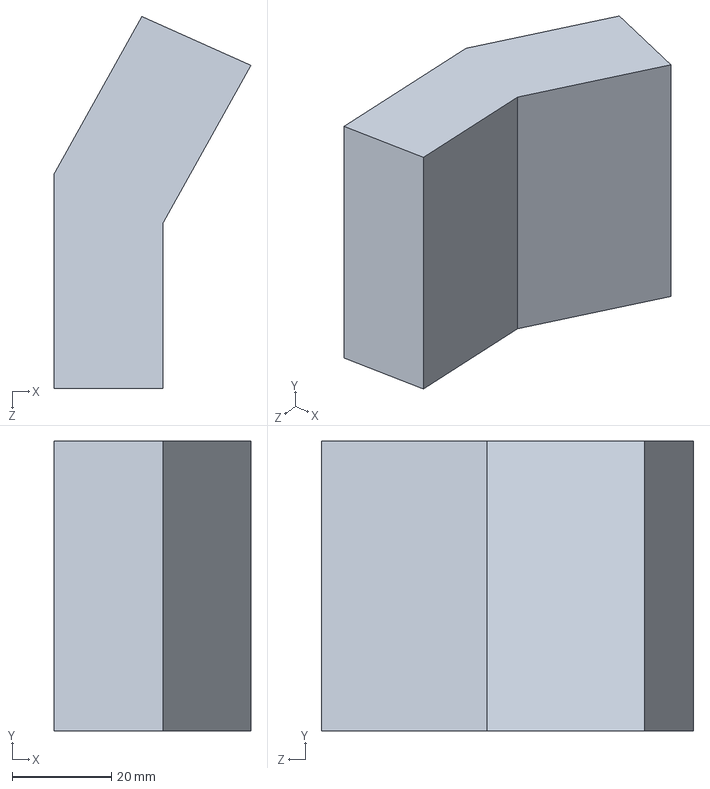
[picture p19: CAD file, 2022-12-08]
CAD and 3D prints/ManipulatorThumb.SLDPRT
39.7 x 58.4 x 75.0 mm

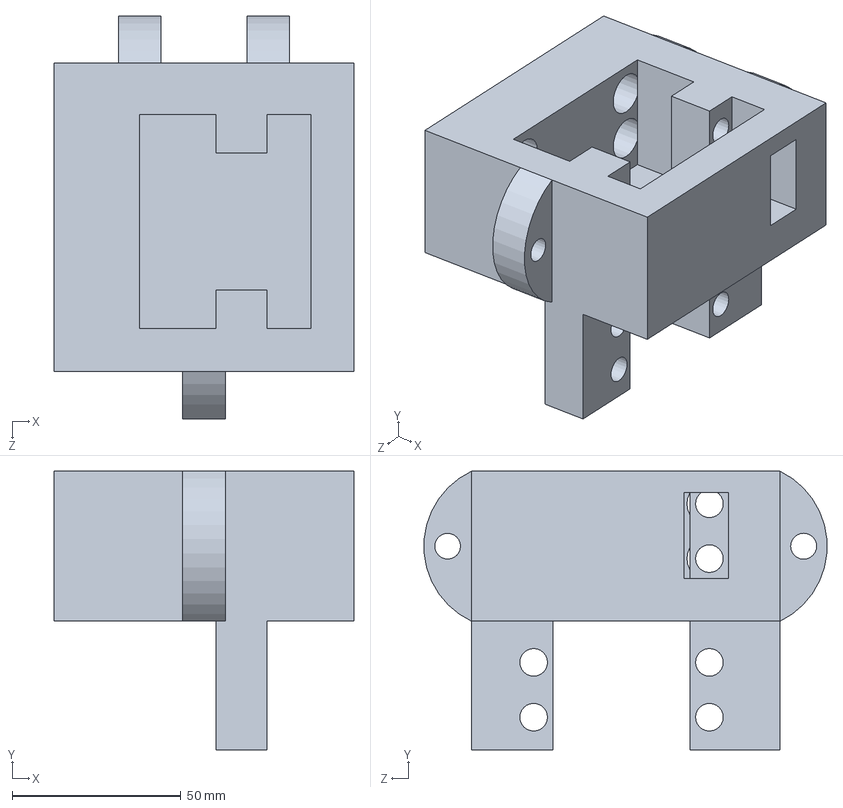
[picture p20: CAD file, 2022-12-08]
CAD and 3D prints/HandPalm.SLDPRT
88.9 x 82.6 x 119.4 mm

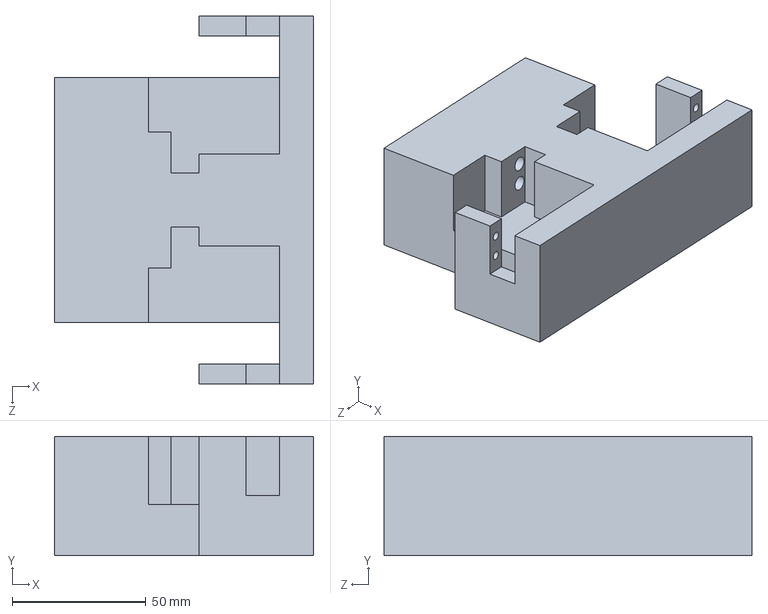
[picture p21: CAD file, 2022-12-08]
CAD and 3D prints/HandPalmV2.SLDPRT
96.6 x 44.5 x 137.2 mm

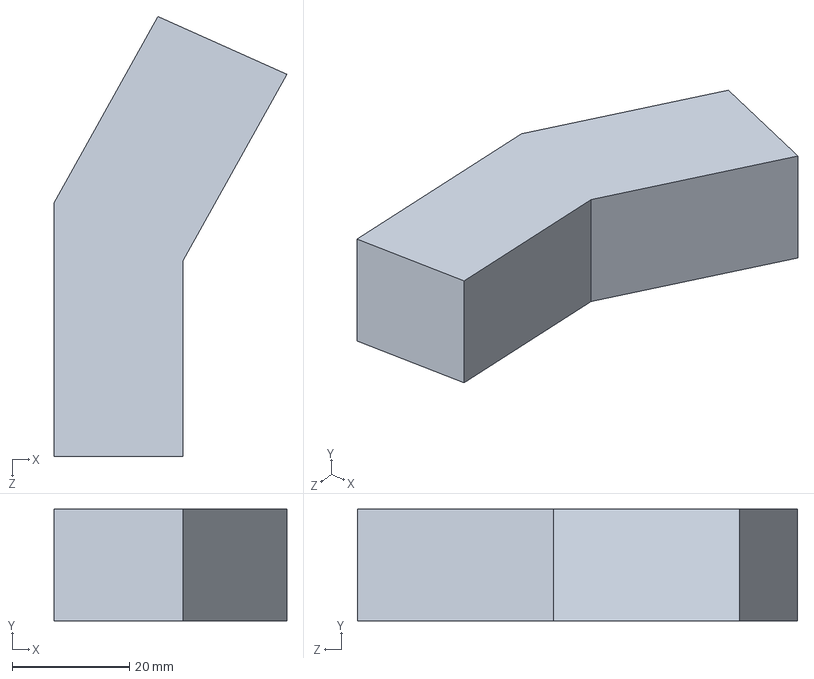
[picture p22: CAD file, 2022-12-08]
CAD and 3D prints/Fingers.SLDPRT
39.7 x 19.1 x 75.0 mm

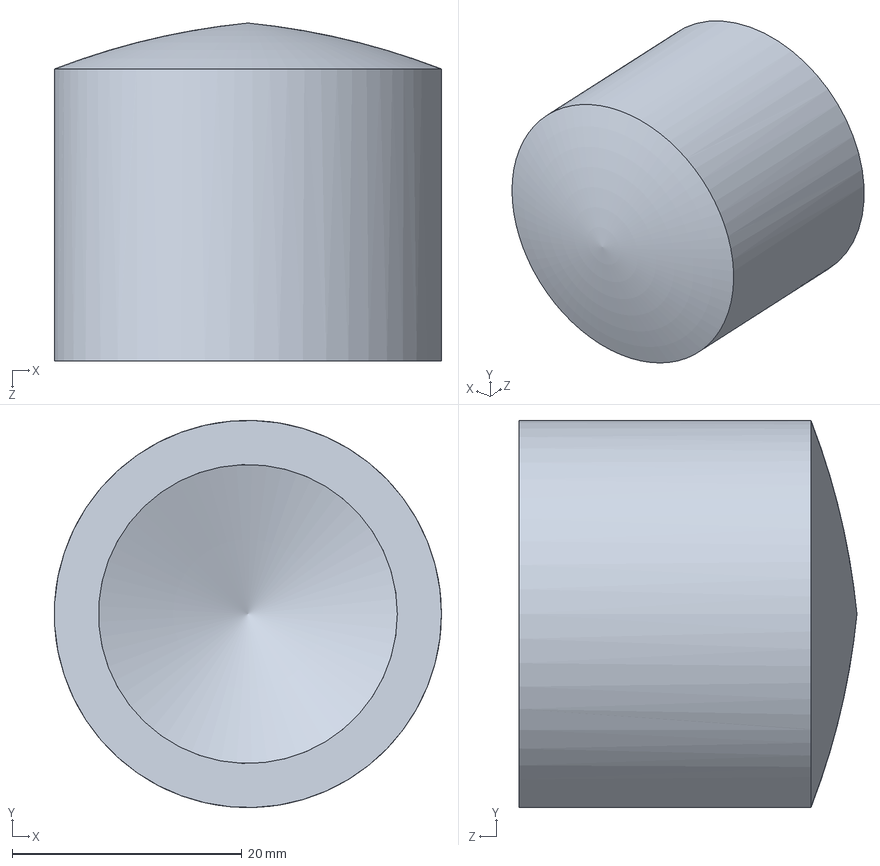
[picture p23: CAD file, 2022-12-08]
CAD and 3D prints/thumb.SLDPRT
33.7 x 33.7 x 29.4 mm

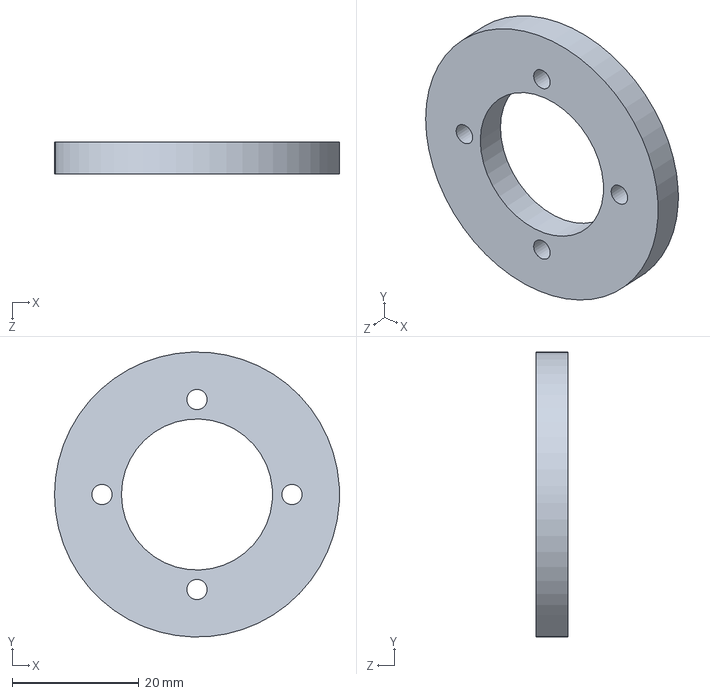
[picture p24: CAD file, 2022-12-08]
CAD and 3D prints/motorspacer.SLDPRT
45.0 x 45.0 x 5.00 mm

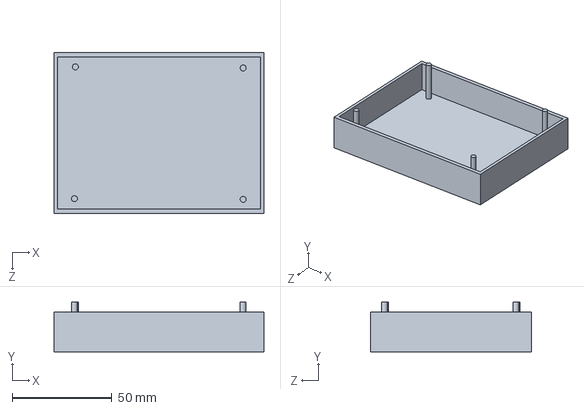
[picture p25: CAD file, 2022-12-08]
CAD and 3D prints/pcbcasebot.SLDPRT
105.3 x 25.0 x 80.8 mm

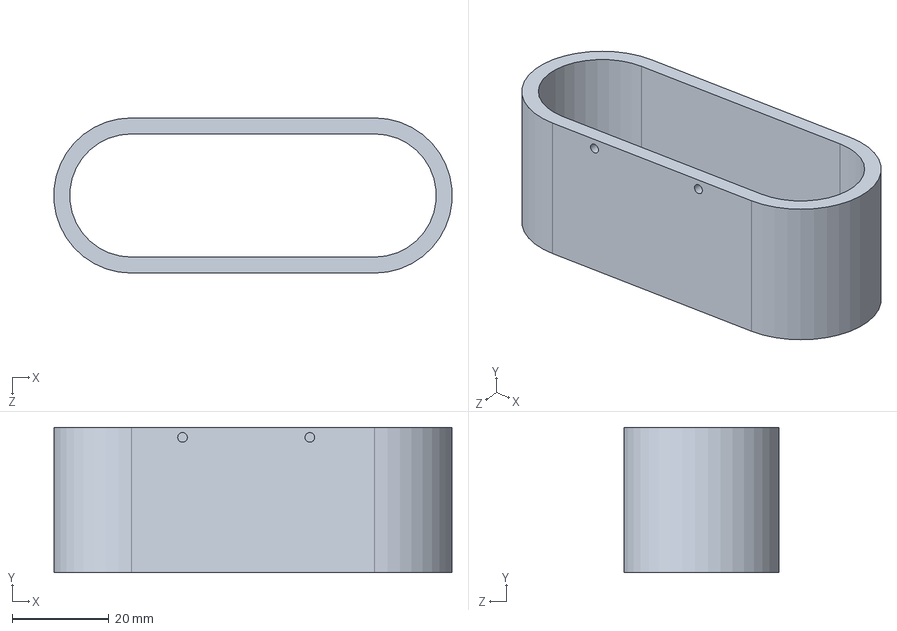
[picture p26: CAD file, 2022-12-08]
CAD and 3D prints/feengor.SLDPRT
82.1 x 30.0 x 32.0 mm

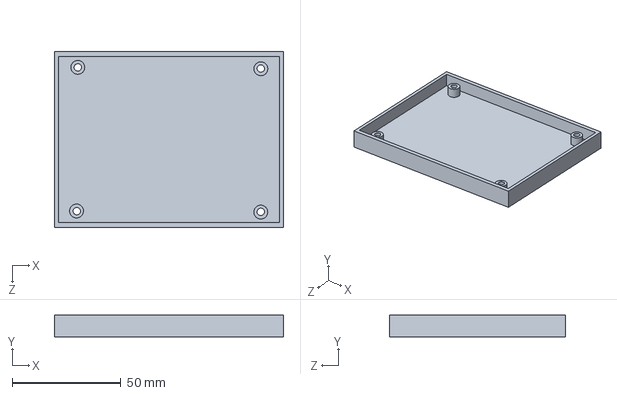
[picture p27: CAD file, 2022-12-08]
CAD and 3D prints/pcbcasetop.SLDPRT
105.3 x 10.0 x 80.8 mm

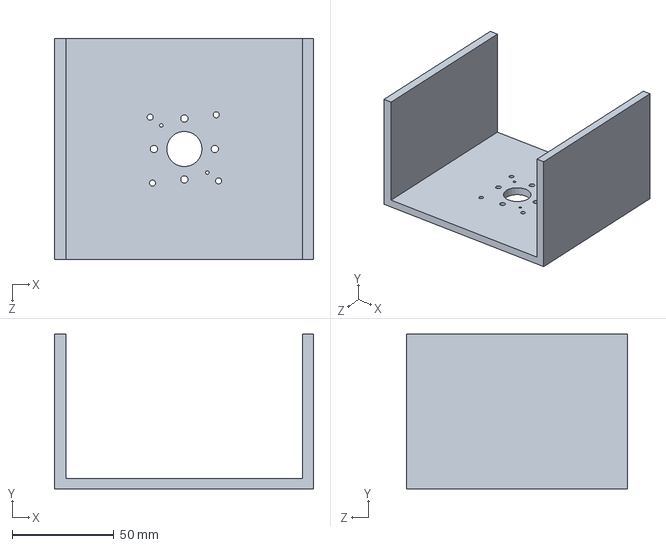
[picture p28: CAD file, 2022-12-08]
CAD and 3D prints/Motor test mount v1.SLDPRT
127.5 x 76.2 x 108.6 mm

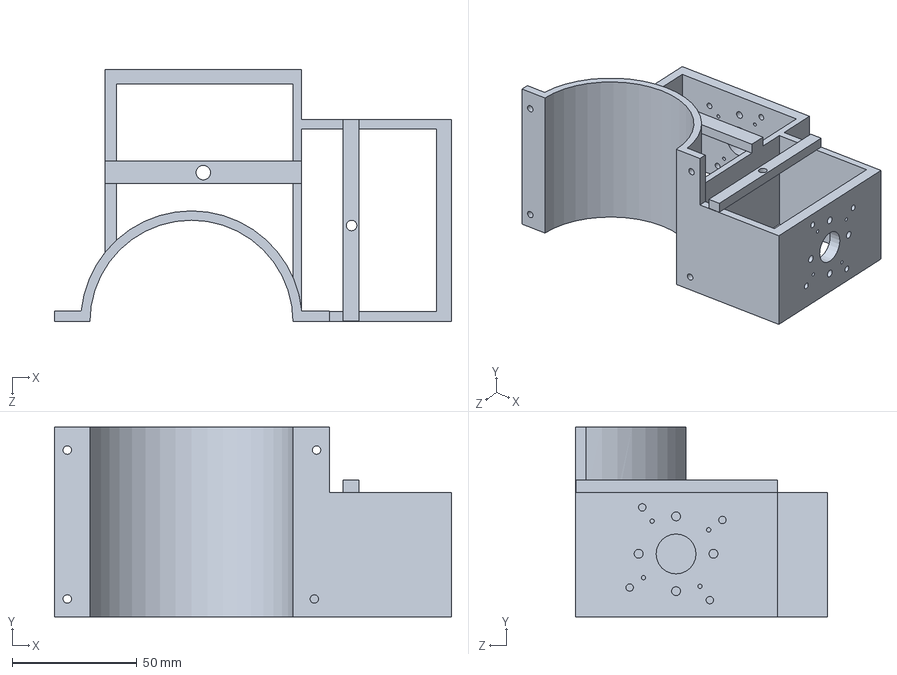
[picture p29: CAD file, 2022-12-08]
CAD and 3D prints/sleeve clearance.SLDPRT
159.2 x 76.2 x 101.2 mm

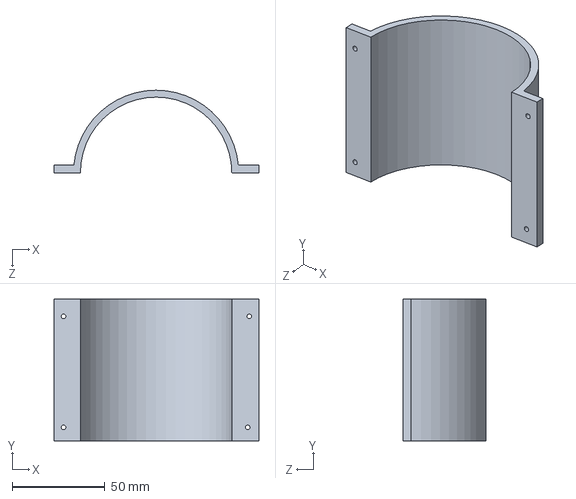
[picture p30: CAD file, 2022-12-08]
CAD and 3D prints/sleeve tapSLDPRT.SLDPRT
110.3 x 76.2 x 44.5 mm

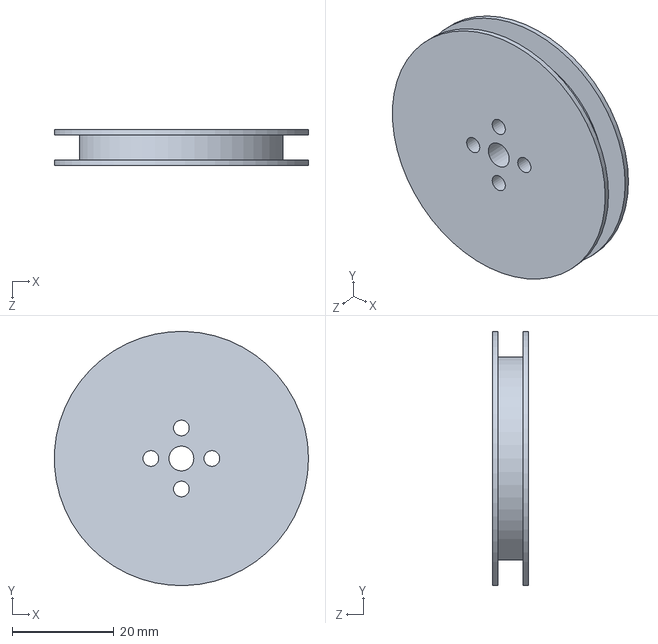
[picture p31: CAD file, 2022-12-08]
CAD and 3D prints/pulley.SLDPRT
50.0 x 50.0 x 7.00 mm

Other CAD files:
CAD and 3D prints/Motor test mount v1.STL
CAD and 3D prints/feengor.STL
CAD and 3D prints/motorspacer.STL
CAD and 3D prints/pcbcasebot.STL
CAD and 3D prints/pcbcasetop.STL
CAD and 3D prints/pulley.STL
CAD and 3D prints/sleeve clearance.STL
CAD and 3D prints/sleeve tapSLDPRT.STL
CAD and 3D prints/thumb.STL

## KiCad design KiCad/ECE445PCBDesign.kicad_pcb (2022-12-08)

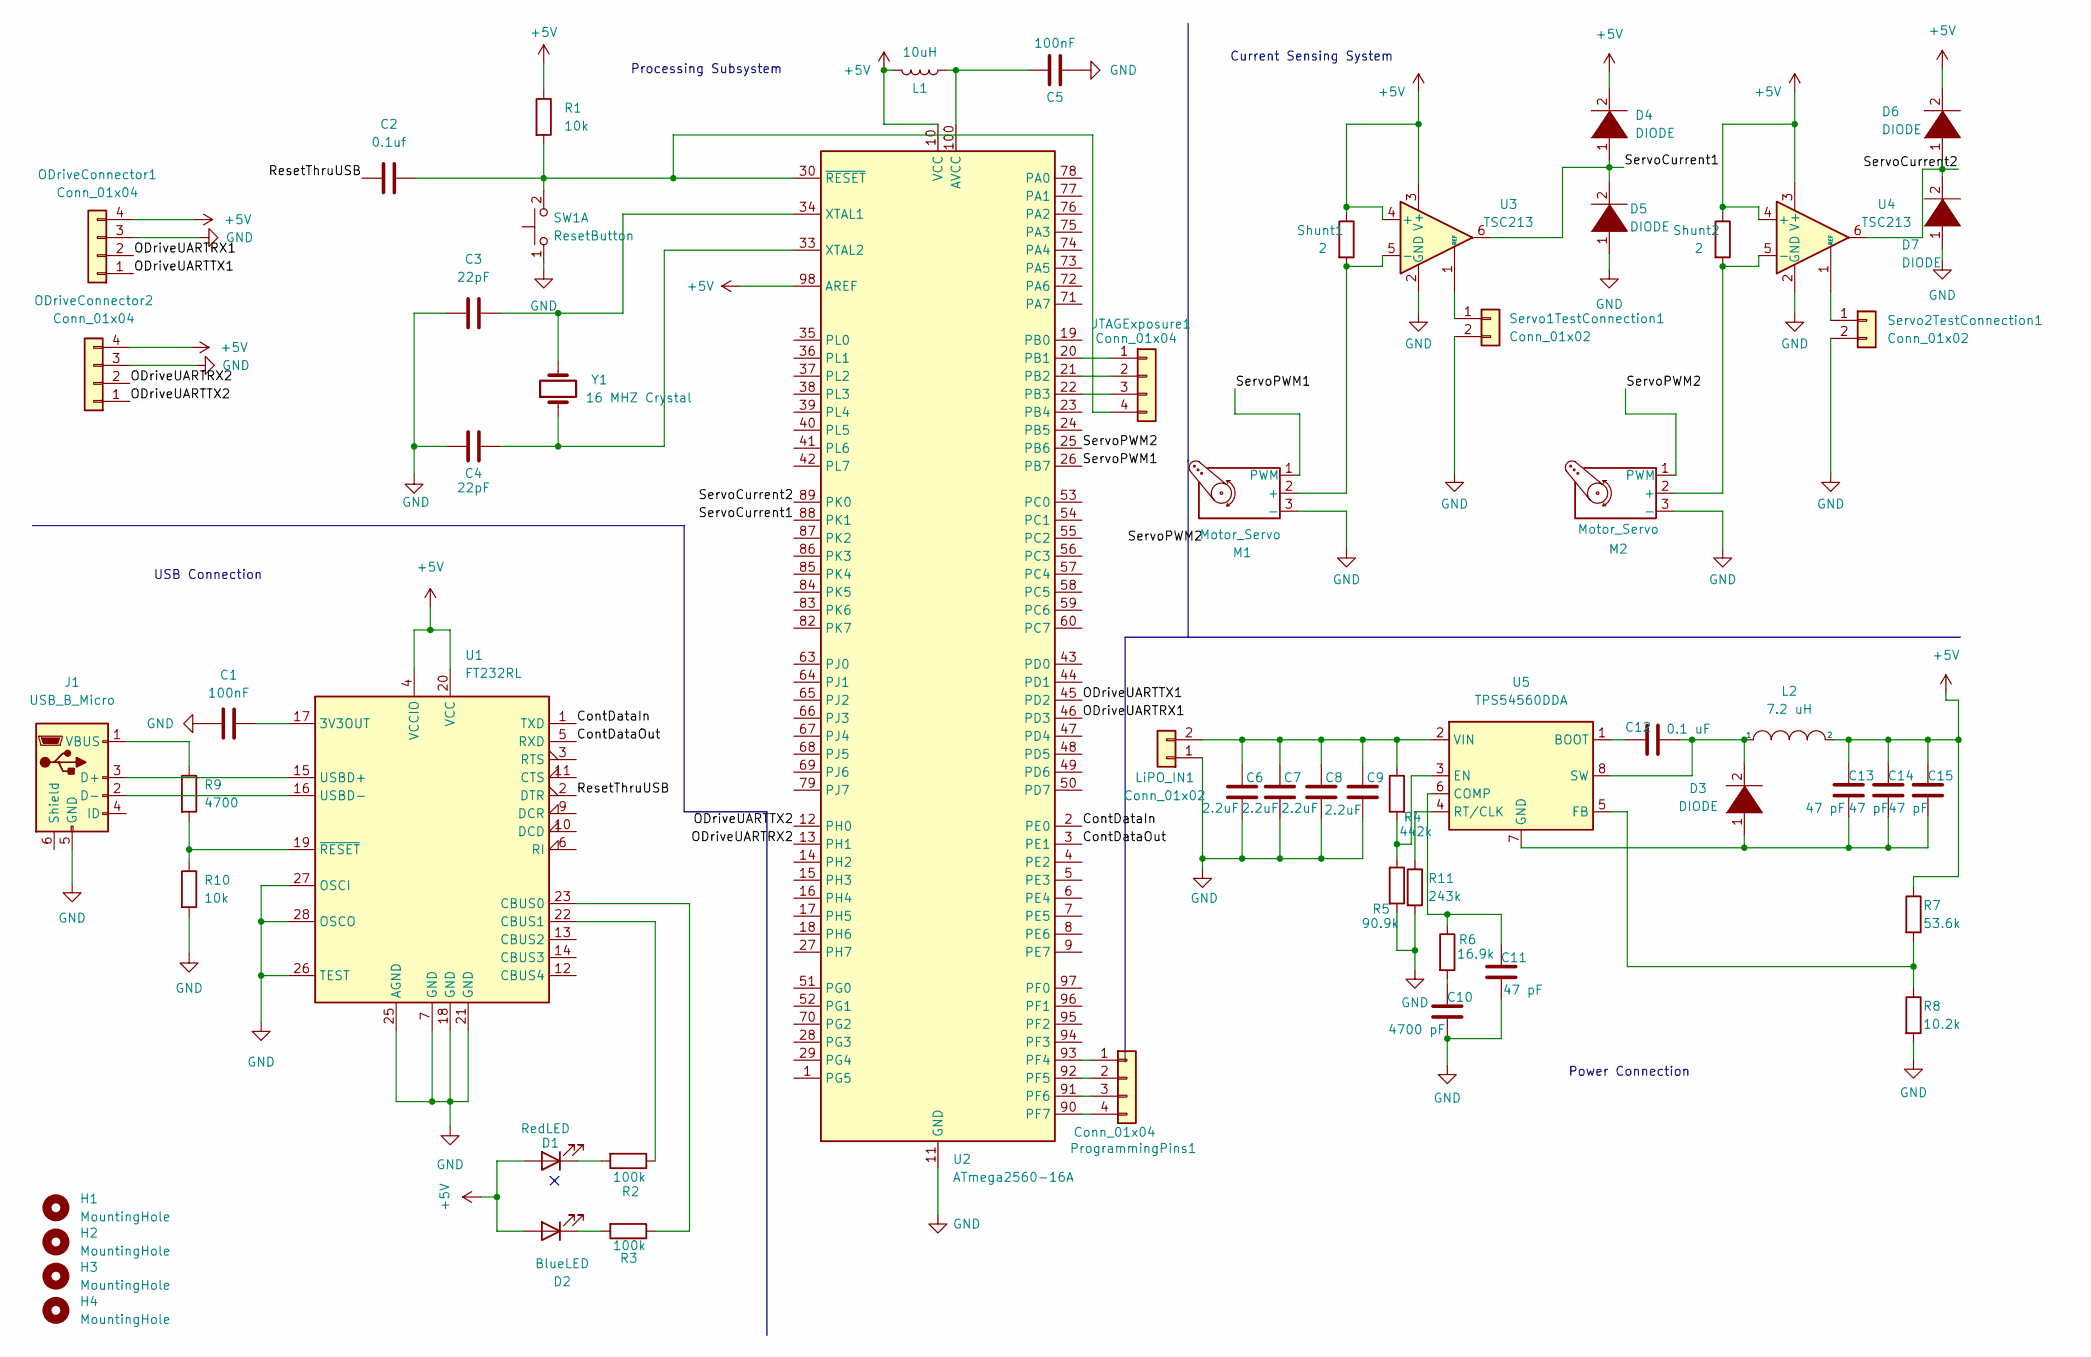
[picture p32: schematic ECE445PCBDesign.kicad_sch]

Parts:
C1, C5: 100nF; C_0805_2012Metric_Pad1.18x1.45mm_HandSolder
C2: 0.1uf; C_0805_2012Metric_Pad1.18x1.45mm_HandSolder
C3, C4: 22pF; C_0805_2012Metric_Pad1.18x1.45mm_HandSolder
C6, C7, C8, C9: 2.2uF; C_0805_2012Metric_Pad1.18x1.45mm_HandSolder
C10: 4700 pF; C_0805_2012Metric_Pad1.18x1.45mm_HandSolder
C11, C13, C14, C15: 47 pF; C_0805_2012Metric_Pad1.18x1.45mm_HandSolder
C12: 0.1 uF; C_0805_2012Metric_Pad1.18x1.45mm_HandSolder
D1: RedLED; D_0603_1608Metric_Pad1.05x0.95mm_HandSolder
D2: BlueLED; D_0603_1608Metric_Pad1.05x0.95mm_HandSolder
D3, D4, D5, D6, D7: DIODE; Vishay-B360A-E3_61T-0-0-0
H1, H2, H3, H4: MountingHole; MountingHole_3.2mm_M3
J1: USB_B_Micro; USB_Mini-B_AdamTech_MUSB-B5-S-VT-TSMT-1_SMD_Vertical
JTAGExposure1: Conn_01x04; Molex_KK-254_AE-6410-04A_1x04_P2.54mm_Vertical
L1: 10uH; L_0603_1608Metric_Pad1.05x0.95mm_HandSolder
L2: 7.2 uH; WE-PDF59
LiPO_IN1: Conn_01x02; SolderWire-2sqmm_1x02_P7.8mm_D2mm_OD3.9mm
M1, M2: Motor_Servo; Molex_KK-254_AE-6410-03A_1x03_P2.54mm_Vertical
ODriveConnector1, ODriveConnector2: Conn_01x04; Molex_KK-254_AE-6410-04A_1x04_P2.54mm_Vertical
ProgrammingPins1: Conn_01x04; Molex_KK-254_AE-6410-04A_1x04_P2.54mm_Vertical
R1, R10: 10k; R_0805_2012Metric_Pad1.20x1.40mm_HandSolder
R2, R3: 100k; R_0805_2012Metric_Pad1.20x1.40mm_HandSolder
R4: 442k; R_0805_2012Metric_Pad1.20x1.40mm_HandSolder
R5: 90.9k; R_0805_2012Metric_Pad1.20x1.40mm_HandSolder
R6: 16.9k; R_0805_2012Metric_Pad1.20x1.40mm_HandSolder
R7: 53.6k; R_0805_2012Metric_Pad1.20x1.40mm_HandSolder
R8: 10.2k; R_0805_2012Metric_Pad1.20x1.40mm_HandSolder
R9: 4700; R_0805_2012Metric_Pad1.20x1.40mm_HandSolder
R11: 243k; R_0805_2012Metric_Pad1.20x1.40mm_HandSolder
SW1: ResetButton; SW_Push_1P1T_NO_6x6mm_H9.5mm
Servo1TestConnection1, Servo2TestConnection1: Conn_01x02; Molex_KK-254_AE-6410-02A_1x02_P2.54mm_Vertical
Shunt1, Shunt2: 2; R_0805_2012Metric_Pad1.20x1.40mm_HandSolder
U1: FT232RL; SSOP-28_5.3x10.2mm_P0.65mm
U2: ATmega2560-16A; TQFP-100_14x14mm_P0.5mm
U3, U4: TSC213; TSC213ICT
U5: TPS54560DDA; Texas_R-PDSO-G8_EP2.95x4.9mm_Mask2.4x3.1mm_ThermalVias
Y1: 16 MHZ Crystal; 830058383B

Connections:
+5V: C13.2, C14.2, C15.2, D1.2 (A), D2.2 (A), D4.2 (A), D6.2 (A), L1.2, L2.2, ODriveConnector1.4, ODriveConnector2.4, R1.1, R7.1, Shunt1.1, Shunt2.1, U1.4 (VCCIO), U1.20 (VCC), U2.10 (VCC), U2.31 (VCC), U2.61 (VCC), U2.80 (VCC), U2.98 (AREF), U3.3 (V+), U3.4 (+), U4.3 (V+), U4.4 (+)
/ContDataIn: U1.1 (TXD), U2.2 (PE0)
/ContDataOut: U1.5 (RXD), U2.3 (PE1)
/ODriveUARTRX1: ODriveConnector1.2, U2.46 (PD3)
/ODriveUARTRX2: ODriveConnector2.2, U2.13 (PH1)
/ODriveUARTTX1: ODriveConnector1.1, U2.45 (PD2)
/ODriveUARTTX2: ODriveConnector2.1, U2.12 (PH0)
/ResetThruUSB: C2.1, U1.2 (DTR)
/ServoCurrent1: D4.1 (K), D5.2 (A), U2.88 (PK1), U3.6
/ServoCurrent2: D6.1 (K), D7.2 (A), U2.89 (PK0), U4.6
/ServoPWM1: M1.1 (PWM), U2.26 (PB7)
/ServoPWM2: M2.1 (PWM), U2.25 (PB6)
GND: C1.1, C3.1, C4.1, C5.2, C6.1, C7.1, C8.1, C9.1, C10.1, C11.1, D5.1 (K), D7.1 (K), J1.5 (GND), LiPO_IN1.1, M1.3 (-), M2.3 (-), ODriveConnector1.3, ODriveConnector2.3, R5.2, R8.2, R10.2, R11.2, SW1.1 (C), Servo1TestConnection1.2, Servo2TestConnection1.2, U1.7 (GND), U1.18 (GND), U1.21 (GND), U1.25 (AGND), U1.26 (TEST), U1.27 (OSCI), U1.28 (OSCO), U2.11 (GND), U2.32 (GND), U2.62 (GND), U2.81 (GND), U2.99 (GND), U3.2 (GND), U4.2 (GND)
unnamed: C1.2, U1.17 (3V3OUT)
unnamed: C2.2, JTAGExposure1.4, R1.2, SW1.2 (D), U2.30 (~RESET)
unnamed: C3.2, U2.34 (XTAL1), Y1.2
unnamed: C4.2, U2.33 (XTAL2), Y1.1
unnamed: C5.1, L1.1, U2.100 (AVCC)
unnamed: C6.2, C7.2, C8.2, C9.2, LiPO_IN1.2, R4.1, U5.2 (VIN)
unnamed: C10.2, R6.2
unnamed: C11.2, R6.1, U5.6 (COMP)
unnamed: C12.1, D3.2 (A), L2.1, U5.8 (SW)
unnamed: C12.2, U5.1 (BOOT)
unnamed: C13.1, C14.1, C15.1, D3.1 (K), U5.7 (GND), U5.9 (GND)
unnamed: D1.1 (K), R2.2
unnamed: D2.1 (K), R3.2
unnamed: M1.2 (+), Shunt1.2, U3.5 (-)
unnamed: M2.2 (+), Shunt2.2, U4.5 (-)
unnamed: R2.1, U1.22 (CBUS1)
unnamed: R3.1, U1.23 (CBUS0)
unnamed: R4.2, R5.1, U5.3 (EN)
unnamed: R7.2, R8.1, U5.5 (FB)
unnamed: J1.1 (VBUS), R9.1
unnamed: Servo1TestConnection1.1, U3.1 (REF)
unnamed: Servo2TestConnection1.1, U4.1 (REF)
unnamed: J1.3 (D+), U1.15 (USBD+)
unnamed: J1.2 (D-), U1.16 (USBD-)
unnamed: R9.2, R10.1, U1.19 (~RESET)
unnamed: JTAGExposure1.1, U2.20 (PB1)
unnamed: JTAGExposure1.2, U2.21 (PB2)
unnamed: JTAGExposure1.3, U2.22 (PB3)
unnamed: ProgrammingPins1.4, U2.90 (PF7)
unnamed: ProgrammingPins1.3, U2.91 (PF6)
unnamed: ProgrammingPins1.2, U2.92 (PF5)
unnamed: ProgrammingPins1.1, U2.93 (PF4)
unnamed: R11.1, U5.4 (RT/CLK)

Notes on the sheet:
Processing Subsystem
Power Connection
USB Connection
Current Sensing System

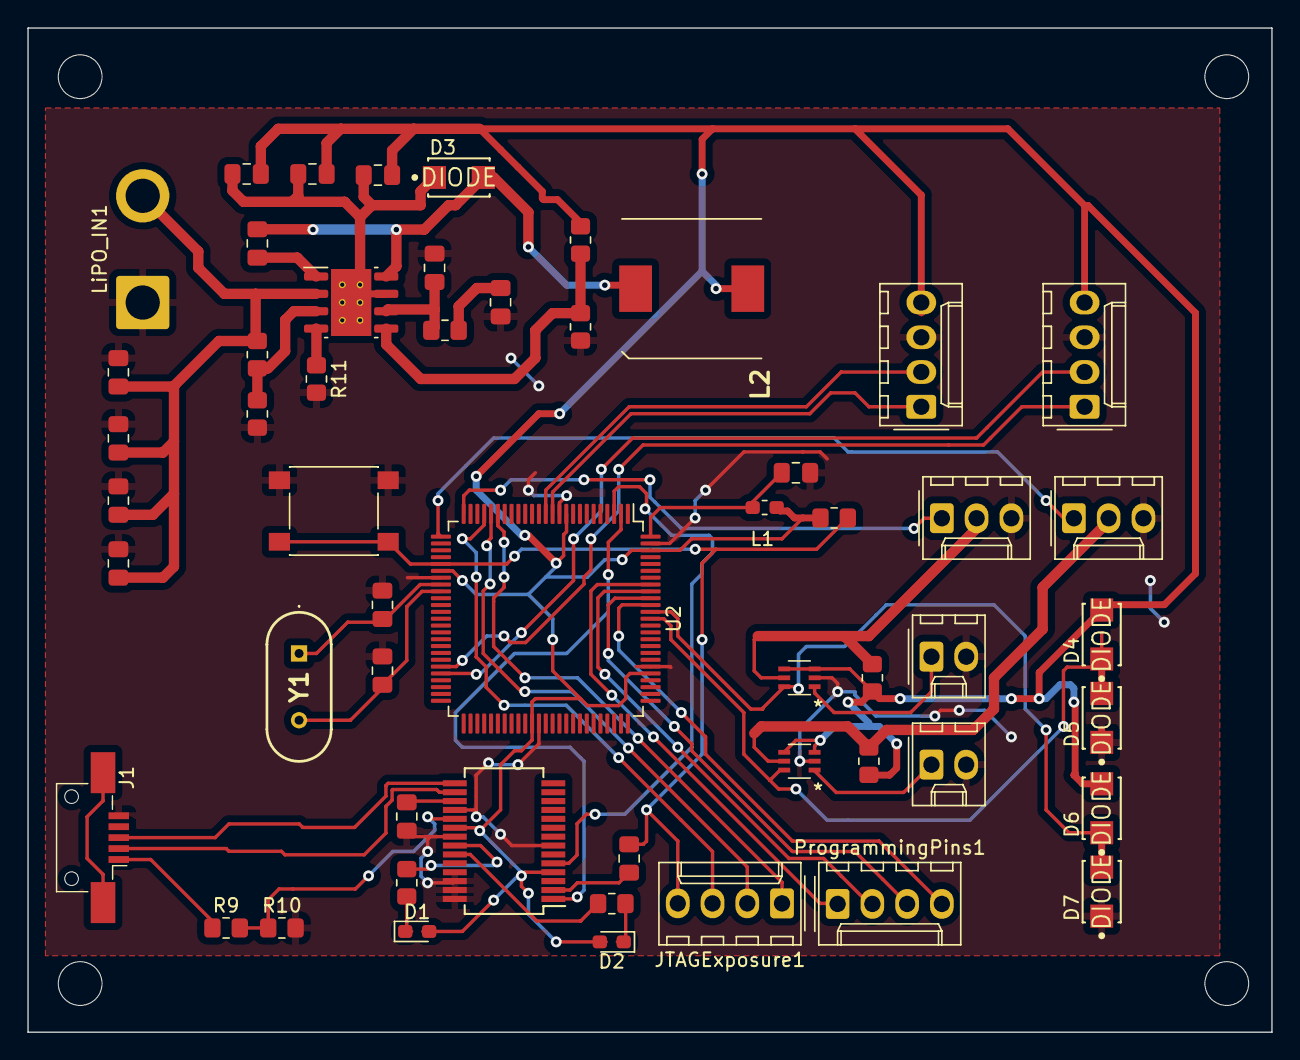
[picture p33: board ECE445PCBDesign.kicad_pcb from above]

Board: 2 copper layers, 90.9 x 73.4 mm, 58 parts (0 on the bottom side), 46 nets.

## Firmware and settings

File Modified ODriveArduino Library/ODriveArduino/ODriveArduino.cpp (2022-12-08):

#include "Arduino.h"
#include "ODriveArduino.h"

// Print with stream operator
template<class T> inline Print& operator <<(Print &obj,     T arg) { obj.print(arg);    return obj; }
template<>        inline Print& operator <<(Print &obj, float arg) { obj.print(arg, 4); return obj; }

ODriveArduino::ODriveArduino(Stream& serial)
    : serial_(serial) {}

void ODriveArduino::SetPosition(int motor_number, float position) {
    SetPosition(motor_number, position, 0.0f, 0.0f);
}

void ODriveArduino::SetPosition(int motor_number, float position, float velocity_feedforward) {
    SetPosition(motor_number, position, velocity_feedforward, 0.0f);
}

void ODriveArduino::SetPosition(int motor_number, float position, float velocity_feedforward, float current_feedforward) {
    serial_ << "p " << motor_number  << " " << position << " " << velocity_feedforward << " " << current_feedforward << "\n";
}

void ODriveArduino::SetVelocity(int motor_number, float velocity) {
    SetVelocity(motor_number, velocity, 0.0f);
}

void ODriveArduino::SetVelocity(int motor_number, float velocity, float current_feedforward) {
    serial_ << "v " << motor_number  << " " << velocity << " " << current_feedforward << "\n";
}

void ODriveArduino::SetCurrent(int motor_number, float current) {
    serial_ << "c " << motor_number << " " << current << "\n";
}

void ODriveArduino::TrapezoidalMove(int motor_number, float position) {
    serial_ << "t " << motor_number << " " << position << "\n";
}

float ODriveArduino::readFloat() {
    return readString().toFloat();
}

float ODriveArduino::GetVelocity(int motor_number) {
	serial_<< "r axis" << motor_number << ".encoder.vel_estimate\n";
	return ODriveArduino::readFloat();
}

float ODriveArduino::GetPosition(int motor_number) {
    serial_ << "r axis" << motor_number << ".pos_vel_mapper.pos_rel\n";
    return ODriveArduino::readFloat();
}

int32_t ODriveArduino::readInt() {
    return readString().toInt();
}

bool ODriveArduino::run_state(int axis, int requested_state, bool wait_for_idle, float timeout) {
    int timeout_ctr = (int)(timeout * 10.0f);
    serial_ << "w axis" << axis << ".requested_state " << requested_state << '\n';
    if (wait_for_idle) {
        do {
            delay(100);
            serial_ << "r axis" << axis << ".current_state\n";
        } while (readInt() != AXIS_STATE_IDLE && --timeout_ctr > 0);
    }

    return timeout_ctr > 0;
}

String ODriveArduino::readString() {
    String str = "";
    static const unsigned long timeout = 1000;
    unsigned long timeout_start = millis();
    for (;;) {
        while (!serial_.available()) {
            if (millis() - timeout_start >= timeout) {
                return str;
            }
        }
        char c = serial_.read();
        if (c == '\n')
            break;
        str += c;
    }
    return str;
}

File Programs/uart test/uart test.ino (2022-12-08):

#include <ODriveArduino.h>
#include <ODriveEnums.h>
#include <Servo.h> 

#include <ODriveEnums.h>

#include <HardwareSerial.h>
#include <ODriveArduino.h>
// Printing with stream operator helper functions
template<class T> inline Print& operator <<(Print &obj,     T arg) { obj.print(arg);    return obj; }
template<>        inline Print& operator <<(Print &obj, float arg) { obj.print(arg, 4); return obj; }
HardwareSerial& odrive_serial1 = Serial1;
HardwareSerial& odrive_serial2 = Serial2;
ODriveArduino odrive1(odrive_serial1);
ODriveArduino odrive2(odrive_serial2);
Servo myservo1;
Servo myservo2;

int requested_state = AXIS_STATE_IDLE;
long previousmillis = 0;

void setup() {
  // put your setup code here, to run once:
  odrive_serial1.begin(115200);
  odrive_serial2.begin(115200);
  Serial.begin(115200);
  myservo1.attach(9);
  myservo2.attach(10);
  while (!Serial) ; // wait for Arduino Serial Monitor to open

  Serial.println("ODriveArduino");
  Serial.println("Setting parameters...");
  odrive_serial1 << "w axis0.config.motor.current_soft_max " << 1.0f <<'\n';
  odrive_serial2 << "w axis0.config.motor.current_soft_max " << 1.0f <<'\n';
  requested_state = AXIS_STATE_CLOSED_LOOP_CONTROL;
  //odrive1.run_state(0,requested_state, false);
  //odrive2.run_state(0,requested_state, false);
  
}


void loop() {
  // put your main code here, to run repeatedly:
  //odrive.run_state(0,requested_state, false);
  /*unsigned long currentmillis = millis();
  //Serial.println(currentmillis);

  if(currentmillis - previousmillis > 1000){
    previousmillis=currentmillis;

    if(requested_state == AXIS_STATE_IDLE){
      Serial.println("On");
      requested_state = AXIS_STATE_CLOSED_LOOP_CONTROL;
      odrive.run_state(0,requested_state, false);
    }
    else{
      Serial.println("off");
      requested_state = AXIS_STATE_IDLE;
      odrive.run_state(0,requested_state, false);
    }
  }*/
  Serial.println("On");
  //odrive_serial << "w axis0.config.motor.current_soft_max " << 1.0f <<'\n';
  //delay(1000);
  //odrive_serial << "w axis0.config.motor.current_soft_max " << 10.0f <<'\n';
  //odrive.SetPosition(0,0);
  //delay(500);
  //odrive.SetPosition(0,50);
  /*for (float ph = 0.0f; ph < 6.28318530718f; ph += 0.01f) {
        float pos_m0 = 2.0f * cos(ph);
        float pos_m1 = 2.0f * sin(ph);
        odrive.SetPosition(0, pos_m0);
        odrive.SetPosition(1, pos_m1);
        delay(5);
      }*/
      static const unsigned long duration = 10000;
      unsigned long start = millis();
      while(millis() - start < duration) {
        for (int motor = 0; motor < 1; ++motor) {
          Serial << odrive1.GetPosition(motor) << "    " << odrive2.GetPosition(motor) << '\t';
        }
        delay(10);
        Serial << '\n';
        myservo1.write(360*odrive1.GetPosition(0));
        myservo2.write(360*odrive2.GetPosition(0));

      }
      
  //Serial.println("Off");



}

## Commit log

2022-12-08 Adding CAD, programs and library
    [ECE445PCBDesign (4)-B_Cu.gbr, ECE445PCBDesign (4)-B_Mask.gbr, ECE445PCBDesign (4)-B_Paste.gbr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]
2022-12-08 Added remaining manipulator CAD and PCB design
    [ECE445PCBDesign.kicad_pcb, ECE445PCBDesign.kicad_sch, Fingers.SLDPRT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]

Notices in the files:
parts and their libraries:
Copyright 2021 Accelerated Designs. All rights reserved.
